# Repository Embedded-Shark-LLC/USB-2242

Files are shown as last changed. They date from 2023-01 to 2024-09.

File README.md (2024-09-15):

# USB-2242
This is a project to integrate a Logitech&trade; Unifying Receiver internally for laptops.  Specifically, I designed this to fit an M.2 2242 slot (M+B key) for my Thinkpad X1C6 (replacing the WWAN card).

If space permits, any low-power USB device (under 500 mA) can be plugged into this adapter.

## Features
- M.2 2242 form factor for internal installation
- Optional USB-A receptacle solder pads for testing/thicker laptops
- PCB cutout for minimum height when not using USB-A receptacle
- Resettable fuse to avoid overcurrent/short circuit damage

## Concept
Most thin and light laptops have a limited number of USB ports, especially USB-A ports.  Currently, my Thinkpad X1C6 has 2 USB-C and 2 USB-A ports, and I constantly leave my wireless mouse receiver in one of the USB-A ports.

After seeing similar products available for older laptop models, I couldn't find one that fit in my M.2 2242 slot, so I made my own.  All it does is provide 5V power for the USB device and routes the USB data lines according to the [M.2 specification](https://pcisig.com/specifications/pciexpress/M.2_Specification/) (local copy available [here](docs/SPEC_PCIe-M.2-Rev1.0.pdf)).

## Notice
PCB thickness must be 0.8 mm to fit in standard M.2 slots.

## Planned Features
- Separate flex PCB for easier soldering of "floating" USB device

## PCB Renders
|PCB Front|PCB Back|
|---|---|
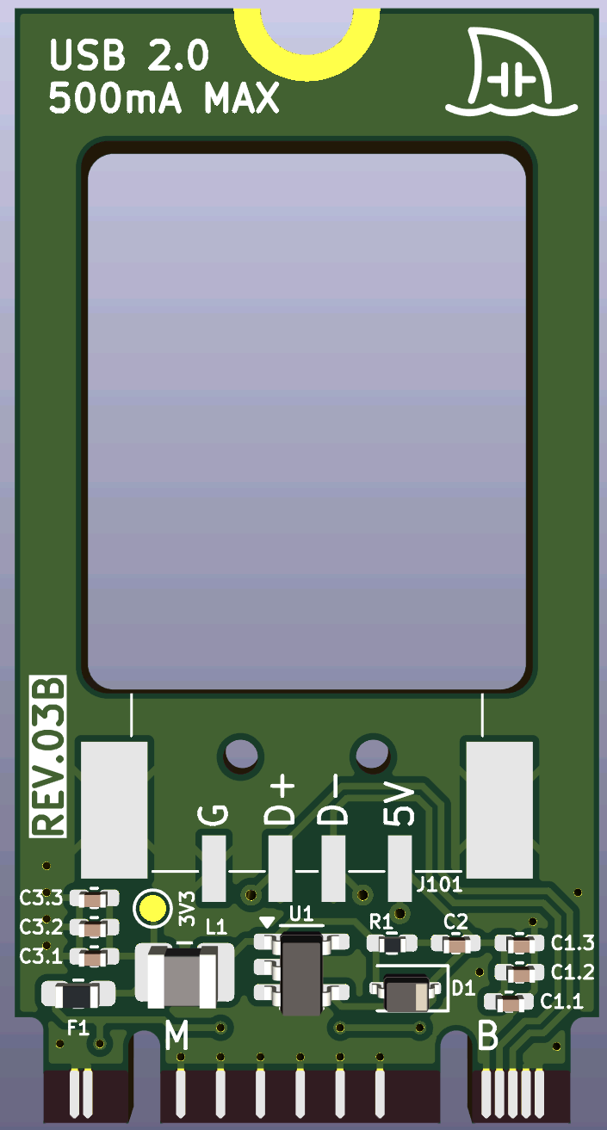
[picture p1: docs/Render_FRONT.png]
PCB front
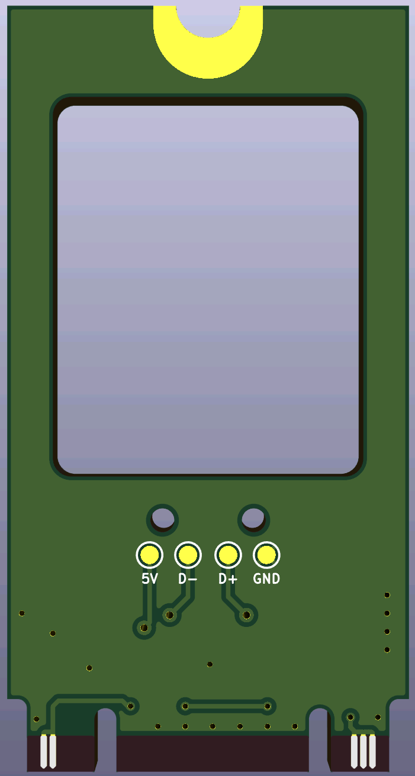
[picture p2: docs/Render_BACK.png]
PCB back
|||

## Trademark Notice
_Logitech, Logi, and their logos are trademarks or registered trademarks of Logitech Europe S.A. and/or its affiliates in the United States and/or other countries._

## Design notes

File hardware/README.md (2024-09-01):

# Hardware

## Major components
| Description | Part Number | Manufacturer | Comments |
| --- | --- | --- | --- |
| USB A port | USB-A-S-RA-TSMT | Adam Tech | SMD, right angle |
| Boost converter | TPS613222ADBVR | Texas Instruments | 5 V,  2.5 A |

## Minor components
| Description | Part Number | Manufacturer | Comments |
| --- | --- | --- | --- |
| Resettable fuse | SMD0603B050TF | YAGEO | 500 mA hold, 1 A trip, 6 V max |
| Schottky diode | CUS15S30,H3F | Toshiba Semiconductor | 30 V, 1.5 A |

## Passive components
| Description | Part Number | Manufacturer | Comments |
| --- | --- | --- | --- |
| 4.99 R resistor | RC0402FR0-74R99L | YAGEO | 0402 |
| 1 nF capacitor | 04025C102KAT2A | KYOCERA | 50 V, X7R, 0402 |
| 100 nF capacitor | CL05A104KA5NNNC | Samsung | 25 V, X5R, 0402 |
| 10 uF capacitor | GRM155R60J106ME05D | Murata Electronics | 6.3 V, X5R, 0402 |
| 22 uF capacitor | CM05X5R226M06AH080 | KYOCERA | 6.3 V, X5R, 0402 |
| 2.2 uH inductor | CIGW252010GL2R2MNE | Samsung | 93 mR DCR, 1008 |

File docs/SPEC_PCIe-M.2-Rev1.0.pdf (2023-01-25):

disclaims all warranties and liability for the use of this document and the information contained herein and assumes no responsibility for any errors that may appear in this document, nor does PCI-SIG make a commitment to update the information

Contact the PCI-SIG office to obtain the latest revision of this specification.
Questions regarding this specification or membership in PCI-SIG may be forwarded to:

Membership Services
www.pcisig.com
E-mail: | administration@pcisig.com
Phone: | 503-619-0569
Fax: | 503-644-6708

Technical Support
techsupp@pcisig.com

DISCLAIMER
This PCI Code and ID Assignment Specification is provided as is with no warranties whatsoever, including any warranty of merchantability, non-infringement, fitness for any particular purpose, or any warranty otherwise arising out of any proposal, specification, or sample. PCI-SIG disclaims all liability for infringement of proprietary rights, relating to use of information in this specification. No license, express or implied, by estoppel or otherwise, to any intellectual property rights is granted herein. PCI Express is a trademark of PCI-SIG.
All other product names are trademarks, registered trademarks, or service marks of their respective owners.
© 2012, 2013 PCI SIG. All rights reserved.

PCI Express M.2 Specification

PCI Express M.2 Specification | | 3
Revision 1.0, November 1, 2013

## Revision History

Rev | Version | History | Date
1.0 | | Initial Release | November 1, 2013

PCI Express M.2 Specification

PCI Express M.2 Specification | | 4

## Table of Contents

PCI Express M.2 Specification

PCI Express M.2 Specification | | 5
2.4.7. Top Side Connection | 63
2.4.7.1. Top Side Connector Physical Dimensions | 63
2.4.7.2. Top Side Connection Total System Length | 65
2.4.7.3. Top Side Connection Stack-up | 66
2.4.7.3.1. Single Sided Module (Using H2.3 Connector) | 66
2.4.7.3.2. Single Sided Module (Using H2.5 Connector) | 67
2.4.7.3.3. Double Sided Module (Using H2.8, H3.2 and H4.2 Connector) | 68
2.4.7.4. Top Side Connector Layout Pattern | 70
2.4.8. Mid Line Connection (Using M1.8 Connector) | 71
2.4.8.1. Mid Line Connector Physical Dimensions | 71
2.4.8.2. Mid Line Connection Total System Length | 72
2.4.8.3. Mid Line Connection Stack-up | 73
2.4.8.3.1. Single-sided Module | 73
2.4.8.3.2. Double-sided Module | 74
2.4.8.4. Mid Line Connector Layout Pattern | 76
2.4.9. Connector Key Dimension | 78
2.4.9.1. Host Connector Keying | 78
2.5. Module Stand-off | 81
2.5.1. Recommended Main Board Hole | 81
2.5.2. Electrical Ground Path | 81
2.5.3. Thermal Ground Path | 81
2.5.4. Stand-Off Guidelines | 84
2.5.4.1. Stand-Off Guidelines Option 1 | 84
2.5.4.2. Stand-Off Guidelines Option 2 | 85
2.5.5. Screw Selection Guideline | 86
2.5.5.1. Option 1, Wafer-Head Style M3 Screw | 86
2.5.5.2. Option 2, M3 Screw with Tapered Shaft | 87
2.5.5.3. Option 3, Wafer-Head Style M2 Screw | 87
2.5.5.4. Option 4, Flat-Head Style M3 Screw | 88
2.6. Thermal Guidelines for the M.2 | 89
2.6.1. Objective | 89
2.6.2. Introduction to Thermal Management | 89
2.6.2.1. Thermal Design Power Definition | 89
2.6.2.2. Skin Temperature Definition | 90
2.6.2.3. Unpowered M.2 Module Temperature | 90
2.6.2.4. System Skin Temperature—Fan-based System | 90
2.6.3. System Skin Temperature—Fanless System | 91
2.6.4. Examples of Dissipation (TDP) Response of Modules | 91

### 3. Electrical Specifications | 92

3.1. Connectivity Socket 1 Module Interface Signals | 92
3.1.1. Power Sources and Grounds | 95

PCI Express M.2 Specification

PCI Express M.2 Specification | | 6
3.1.2. PCI Express Interface | 95
3.1.3. PCI Express Auxiliary Signals | 96
3.1.3.1. Reference Clock | 96
3.1.3.2. CLKREQ# Signal | 96
3.1.3.2.1. Power-up Requirements | 98
3.1.3.2.2. Dynamic Clock Control | 98
3.1.3.3. Clock Request Support Reporting and Enabling | 100
3.1.3.4. PERST# Signal | 100
3.1.3.5. PEWAKE# Signal | 100
3.1.4. USB Interface | 101
3.1.5. Display Port Interface | 101
3.1.5.1. DP_HPD | 101
3.1.5.2. DP_MLDIR | 101
3.1.6. SDIO Interface | 102
3.1.7. UART Interface | 104
3.1.7.1. UART_WAKE# | 105
3.1.8. PCM/I2S Interface | 105
3.1.9. I2C Interface | 106
3.1.9.1. ALERT# Signal | 106
3.1.9.2. I2C_DATA Signal | 106
3.1.9.3. I2C_CLOCK Signal | 106
3.1.10. NFC Supplemental UIM Interface | 106
3.1.10.1. UIM POWER SRC | 106
3.1.10.2. UIM POWER SNK | 107
3.1.10.3. UIM SWP | 107
3.1.10.4. NFC Supplemental UIM Interface Wiring Example | 107
3.1.11. Communication Specific Signals | 108
3.1.11.1. Suspend Clock | 108
3.1.11.2. Status Indicators | 108
3.1.11.3. W_DISABLE# Signal | 109
3.1.11.4. Coexistence Signals | 110
3.1.12. Reserved Pins | 111
3.1.13. Vendor Defined | 111
3.1.14. Socket 1 Connector Pin-out Definitions | 111
3.1.15. Socket 1 Based Soldered-down Module Pinouts | 115
3.2. WWAN/SSD/Other Socket 2 Module Interface Signals | 118
3.2.1. Power Sources and Grounds | 121
3.2.2. PCI Express Interface | 121
3.2.3. USB Interface | 121
3.2.4. HSIC Interface | 121
3.2.5. SSIC Interface | 121
3.2.6. USB3.0 Interface | 122

PCI Express M.2 Specification

PCI Express M.2 Specification | | 7
3.2.7. SATA Interface (Informative) | 122
3.2.7.1. DEVSLP | 122
3.2.7.2. DAS/DSS# | 122
3.2.8. User Identity Module (UIM) Interface | 122
3.2.8.1. UIM_PWR | 122
3.2.8.2. UIM_RESET | 123
3.2.8.3. UIM_CLK | 123
3.2.8.4. UIM_DATA | 123
3.2.8.5. SIM_DETECT | 123
3.2.9. Communication-specific Signals | 124
3.2.9.1. Suspend Clock | 124
3.2.9.2. Status Indicators | 124
3.2.9.3. W_DISABLE# Signals | 124
3.2.9.4. Coexistence Signals | 124
3.2.10. Supplemental Communication Specific Signals | 125
3.2.10.1. FULL_CARD_POWER_OFF# | 125
3.2.10.2. RESET# | 125
3.2.10.3. General Purpose Input Output Pins | 126
3.2.10.3.1. GNSS Signals | 127
3.2.10.3.2. Audio Signals | 127
3.2.10.3.3. Second UIM Signals | 127
3.2.10.3.4. IPC[0..7] Signals | 128
3.2.10.3.5. WAKE_ON_WWAN# Signal | 128
3.2.10.4. DPR Signal | 128
3.2.10.5. Antenna Control | 128
3.2.11. SSD Specific Signals | 129
3.2.11.1. Reserved for MFG CLOCK and DATA | 129
3.2.12. Configuration Pins | 129
3.2.13. Socket 2 Connector Pin-out Definitions | 130
3.3. SSD Socket 3 Module Interface Signals | 136
3.3.1. Power and Grounds | 137
3.3.2. PCI Express Interface | 137
3.3.3. SATA Interface (Informative) | 137
3.3.3.1. DEVSLP | 137
3.3.3.2. DAS/DSS# | 137
3.3.4. SSD Specific Signals | 137
3.3.4.1. SUSCLK | 137
3.3.4.2. PEDET | 138
3.3.4.3. Reserved for MFG Clock & Data | 138
3.3.5. Socket 3 Connector Pin-out Definitions | 138

### 4. Electrical Requirements | 141

4.1. 3.3 V Logic Signal Requirements | 141

PCI Express M.2 Specification

PCI Express M.2 Specification | | 8
4.2. 1.8 V Logic Signal Requirements | 142
4.3. Power | 142

### 5. Platform Socket Pin-Out and Key Definitions | 145

5.1. Connectivity Socket; Socket 1 | 146
5.1.1. Socket 1-DP (Mechanical Key A) On Platform | 147
5.1.2. Socket 1-SD (Mechanical Key E) On Platform | 149
5.1.3. Dual Module Key Module: Supports Socket 1-SD and Socket 1-DP | 151
5.2. WWAN+GNSS/SSD/Other Socket; Socket 2 | 151
5.2.1. Socket 2 – Configuration Pin Definitions | 151
5.2.2. Socket 2 Pin-Out (Mechanical Key B) On Platform | 153
5.3. SSD Socket; Socket 3 (Mechanical Key M) | 155
5.4. Soldered Down Pinout Definitions | 156

### 6. Annex | 159

6.1. Glossary | 159
6.2. M.2 Signal Directions | 160
6.3. Signal Integrity Guideline | 162
6.3.1. Test Fixture Requirements | 163
6.3.2. Suggested Top Mount Signal Integrity PCB Layout | 164
6.3.3. Suggested Mid-Plane Signal Integrity PCB Layout | 167
6.4. RF Connector Related Test Setups | 173
6.4.1. VSWR Test Set-up Method for RF Connector Receptacles | 173
6.4.2. Contact Resistance Measurement Setup & Test Procedure Example | 173
6.5. Thermal Guideline Annex | 177
6.5.1. Assumptions | 177
6.5.1.1. Die Thermal Dissipation Overview | 177
6.5.1.2. Component Overview | 178
6.5.2. Generic System Environment Categories (Assumptions) | 179
6.5.2.1. Module Slot Definitions by System | 180
6.5.2.1.1. Systems with Fans | 180
6.5.2.1.2. Systems without Fans | 180
6.5.3. Assessing Thermal Design Power Capability | 181
6.5.3.1. Use Cases | 181
6.5.3.2. Extended Use Cases | 181
6.5.3.3. Unpowered Module | 181
6.5.3.4. Use Case Flexibility | 181
6.5.4. Module Placement Advice | 182
6.5.5. Skin Temperature Sensitivity to Module Power | 182
6.5.6. General Applicability | 182
6.5.7. Generic Assumptions for Module Arrangement | 182
6.5.8. Examples | 183

PCI Express M.2 Specification

PCI Express M.2 Specification | | 9
6.5.8.1. Notebook Category | 183
6.5.8.1.1. Generic Motherboard Assumptions | 184
6.5.8.1.2. System Layout Assumptions | 184
6.5.8.1.3. Local Skin Temperature | 185
6.5.8.1.4. Thermal Design Power Response – Notebook Category | 186
6.5.8.2. Thin Platform Notebook with Fan Category | 188
6.5.8.2.1. Generic Motherboard Assumptions | 189
6.5.8.2.2. System Layout Assumptions | 190
6.5.8.2.3. Module Placement Advice – Thin Platform Notebook | 190
6.5.8.2.4. Local Skin Temperature | 191
6.5.8.2.5. Thermal design Power Response – Thin Platform Notebook with Fan
Category | 192
6.5.8.3. Tablet without Fan Category | 194
6.5.8.3.1. Generic Motherboard Assumptions | 195
6.5.8.3.2. System Layout Assumptions | 196
6.5.8.3.3. Local Skin Temperature | 196
6.5.8.3.4. Thermal Design Power Response—Tablet Category | 198
6.6. Examples of FULL_CARD_POWER_OFF# Sequences (Informative) | 198
6.6.1. Example of Power On/Off Sequence | 198
6.6.2. Example of Tablet Power On/Off Sequence | 198
6.6.3. Example of Very-thin Notebooks Power On/Off Sequence | 199

### Appendix A. Acknowledgments | 200

PCI Express M.2 Specification

PCI Express M.2 Specification | | 10

## List of Figures

PCI Express M.2 Specification

PCI Express M.2 Specification | | 11
Figure 35. | Socket 1 Type 3030/3026 RF Connector Assignment Recommendation | 58
Figure 36. | Angle of Insertion | 62
Figure 37. | Point of Contact | 63
Figure 38. | Top Side Connector Dimensions | 64
Figure 39. | Top Mounting System Length | 65
Figure 40. | H2.3-S1 - Stack-up Top Mount Single-Sided Module for 1.2 Maximum Component Height 66
Figure 41. | H2.3-S2 - Stack-up Top Mount Single Sided Module for 1.35 Maximum Component Height | 66
Figure 42. | H2.3-S3 - Stack-up Top Mount Single Sided Module for 1.50 Maximum Component Height | 66
Figure 43. | H2.5-S1 - Stack-up Top Mount Single-sided Module for 1.20 Maximum Top-side Component Height and with Higher Clearance above Motherboard | 67
Figure 44. | H2.5-S2 - Stack-up Top Mount Single-sided Module for 1.35 Maximum Top-side Component Height and with Higher Clearance above Motherboard | 67
Figure 45. | H2.5-S3 - Stack-up Top Mount Single-sided Module for 1.5 Maximum Top-side Component Height and with Higher Clearance above Motherboard | 67
Figure 46. | H2.8-D4 - Stack-up Top Mount Double-sided Module for 1.5 Maximum Top-side Component Height with 0.7 Maximum Bottom-side Component Height | 68
Figure 47. | H3.2-D1 - Stack-up Top Mount Double-sided Module for 1.20 Maximum Top-side Component Height | 68
Figure 48. | H3.2-D2 - Stack-up Top Mount Double-sided Module for 1.35 Maximum Top-side Component Height | 69
Figure 49. | H3.2-D3 - Stack-up Top Mount Double-sided Module for 1.5 Maximum Top-side Component Height | 69
Figure 50. | H4.2-D5 - Stack-up Top Mount Double-sided Module for 1.5 Maximum Top-side Component Height with 1.5 Maximum Bottom-side Component Height | 69
Figure 51. | Example of Top Mount Motherboard Land Pattern Diagram Key B Shown | 70
Figure 52. | Mid-Line (In-line) Connector Dimensions | 71
Figure 53. | Mid-Line (In-Line) System Length | 72
Figure 54. | Stack-up Mid-Line (In-line) Single Sided (S1) Module for 1.2 Maximum Component Height73
Figure 55. | Stack-up Mid-Line (In-line) Single Sided (S2) Module for 1.35 Maximum Component Height | 73
Figure 56. | Stack-up Mid-Line (In-line) Single Sided (S3) Module for 1.5 Maximum Component Height74
Figure 57. | Stack-up Mid-Line (In-line) Double-sided (D1) Module for 1.2 Maximum Top-side Component Height | 74
Figure 58. | Stack-up Mid-Line (In-line) Double-sided (D2) Module for 1.35 Maximum Top-side Component Height | 75
Figure 59. | Stack-up Mid-Line (In-line) Double-sided (D3) Module for 1.5 Maximum Top-side Component Height | 75
Figure 60. | Stack-up Mid-Line (In-line) Double-sided (D4) Module for 1.5 Maximum Top-side Component Height | 75

PCI Express M.2 Specification

PCI Express M.2 Specification | | 12
Figure 61. | Stack-up Mid-Line (In-line) Double-sided (D5) Module for 1.5 Maximum Top-side and Bottom-side Component Height | 76
Figure 62. | Example of Mid Line Motherboard Land Pattern Diagram – Key B Shown | 77
Figure 63. | Connector Key | 78
Figure 64. | M.2 Connector Keying Diagram | 79
Figure 65. | Dual Module Key Scheme Example | 80
Figure 66. | Mid-Line Module Mounting Interface | 81
Figure 67. | Single-sided Top Mount Solder-down Stand-Off | 82
Figure 68. | Elevated Single-sided Top Mount Solder Stand-Off | 82
Figure 69. | Low Profile Double-sided Top Mount Solder-down Stand-Off | 82
Figure 70. | Double-sided Top Mount Solder-down Stand-Off | 83
Figure 71. | Elevated Double-sided Top Mount Solder-down Stand-off | 83
Figure 72. | Flat Stand-Off | 84
Figure 73. | Shouldered Stand-Off | 85
Figure 74. | Screw Guidelines | 86
Figure 75. | Wafer-Head Style M3 Screw | 86
Figure 76. | M3 Screw with Tapered Shaft | 87
Figure 77. | Wafer-Head Style M2 Screw | 87
Figure 78. | Flat-Head Style M3 Screw | 88
Figure 79. | Power-Up CLKREQ# Timing | 98
Figure 80. | CLKREQ# Clock Control Timings | 99
Figure 81. | SDIO Reset Sequence | 103
Figure 82. | SDIO Power-Up Sequence | 103
Figure 83. | UART Frame Format | 104
Figure 85. | Supplemental NFC Signal Connection Example | 107
Figure 86. | Typical LED Connection Example in Platform/System | 108
Figure 87. | Type 2226 SDIO Based Module-Side Pin-Out | 115
Figure 88. | Type 1216 SDIO Based Module-Side Pin-Out | 116
Figure 89. | Type 3026 Display Port Pinout Extension Over an SDIO Based Module-Side Pin-Out......117
Figure 90. | Typical SIM Detect Circuit Implementation | 124
Figure 91. | WAKE_ON_WWAN# Signal | 128
Figure 92. | Type 2226 LGA Pin-Out Using Socket 1-SD Based Pin-Out on Platform | 156
Figure 93. | Type 1216 LGA Pin-Out Using Socket 1-SD Based Pin-Out on Platform | 157
Figure 94. | Type 3026 LGA Pin-Out Using Socket 1-SD & 1-DP Based Pin-Out on Platform | 158
Figure 95. | UART and PCM Signal Direction and Signal Name Changes | 160
Figure 96. | PCIe Signal Direction and Signal Name Changes | 161

PCI Express M.2 Specification

PCI Express M.2 Specification | | 13
Figure 97. | Suggested Motherboard and Module Board Signals and Ground Pad Layout Guideline ...163
Figure 98. | Suggested Ground Void for Module Simulation | 164
Figure 99. | Suggest Ground Void for Main Board | 164
Figure 100. Top Mount Module Test Fixture PCB Layout | 165
Figure 101. Top Mount Mother Board Test Fixture PCB | 166
Figure 102. Top Mount Connector Test Fixture | 167
Figure 103. Mid Plane Connector Test Fixture | 168
Figure 104. Mid-Plane Module Test Fixture PCB Layout | 169
Figure 105. Mid Plane Mother Board Test Fixture PCB | 170
Figure 106. Detail of Top Side SMA End Launch Connector Pad | 170
Figure 107. Ground Void on Backside | 171
Figure 108. Detail of Mid Plane Vias on Top Side Mother Board | 172
Figure 109. Detail of Ground Void on Mid Plane Bottom Side Mother Board | 172
Figure 110. VSWR Test Setup for Receptacle RF Connector | 173
Figure 111. Contact Resistance Measurement Definitions | 173
Figure 112. Prepared Wires | 174
Figure 113. Prepared Wire with Plug | 175
Figure 114. Example View of Notebook Motherboard | 184
Figure 115. Example View of Edge Vents | 184

Figure 116. Example View of Bottom Vents (vent opening where inside boards are visible through the
| opening) | 185
Figure 117. Example View of Region Over Modules | 185
Figure 118. Example View of Hot Spot Over Modules | 186
Figure 119. Example View of Motherboard for Thin Platform Notebook with Fan | 189
Figure 120. Thin Platform Notebook Layout with Vents and Key Components | 190
Figure 121. Example View of Region and Hot Spots Over Modules | 191
Figure 122. Example View of Region and Hot Spots Under Modules | 192
Figure 123. Example View of Tablet Motherboard | 195
Figure 124. Example View of System Layout, Including Table | 196
Figure 125. Example View of Display Surface Temperature with WWAN Use Case Estimate II | 197

PCI Express M.2 Specification

PCI Express M.2 Specification | | 14

List of Tables

Table 1. | Optional Module Configurations | 24
Table 2. | General Tolerance | 25
Table 3. | Key Location/Pin Block Dimensions for Keys A - F | 40
Table 4. | Key Location/Pin Block Dimensions for Keys G - M | 40
Table 5. | RF Connector Physical Characteristics | 55
Table 6. | RF Connector Mechanical Requirements | 55
Table 7. | RF Connector Electrical Requirements | 56
Table 8. | RF Connector Environmental Requirements | 56
Table 9. | Recommended Antenna Function Allocation Table | 57
Table 10. | Connector/Module Type Supported Matrix | 59
Table 11. | Connector Physical Requirements | 60
Table 12. | Connector Environmental Requirements | 61
Table 13. | Connector Electrical Requirements | 61
Table 14. | Stand-Off Height Descriptor Table | 84
Table 15. | Socket 1 System Interface Signals and Voltage Table | 92
Table 16. | Power-Up CLKREQ# Timings | 98
Table 17. | CLKREQ# Clock Control Timings | 100
Table 18. | DP_MLDIR Pin Termination | 102
Table 19. | SDIO Reset and Power-Up Timing | 103
Table 20. | Simple Indicator Protocol for LED States | 109
Table 21. | Radio Operational States | 110
Table 22. | SDIO Based Module Solution Pinout (Module Key E) | 112
Table 23. | Display Port Based Module Solution Pinout (Module Key A) | 113
Table 24. | Socket 1 Module Pinout with Dual Module Key (A-E) | 114
Table 25. | Socket 2 System Interface Signal Table | 118
Table 26. | GPIO pin Function Assignment per Port Configuration | 126
Table 27. | Socket 2 Module Configuration | 129
Table 28. | Socket 2 SSIC-based WWAN Module Pinout | 131
Table 29. | Socket 2 USB3.0-based WWAN Module Pinout | 131
Table 30. | Socket 2 PCIe-based WWAN Module Pinout | 133
Table 31. | Socket 2 SATA-based SSD Module Pinout | 134
Table 32. | Socket 2 PCIe-based SSD Module Pinout | 135
Table 33. | Socket 3 System Interface Signal Table | 136

PCI Express M.2 Specification

PCI Express M.2 Specification | | 15
Table 34. | Socket 3 SATA-based Module Pinout | 139
Table 35. | Socket 3 PCIe-based Module Pinout | 140
Table 36. | DC Specification for 3.3 V Logic Signaling | 141
Table 37. | DC Specification for 1.8 V Logic Signaling | 142
Table 38. | Key Regulated Power Rail Parameters | 143
Table 39. | Power Rail Settling Time | 143
Table 40. | Key VBAT Power Rail Parameters | 143
Table 41. | Power Rating Table for the Various Modules and Connector Keys | 144
Table 42. | Mechanical Key Assignments | 146
Table 43. | Socket 1 Versions | 147
Table 44. | Socket 1-DP Pin-Out Diagram (Mechanical Key A) On Platform | 148
Table 45. | Socket 1-SD Pin-Out Diagram (Mechanical Key E) On Platform | 150
Table 46. | Socket 2 Module Configuration Table | 152
Table 47. | Socket 2 Pinout Diagram (Mechanical Key B) | 154
Table 48. | Socket 3 SSD Pin-Out (Mechanical Key M) On Platform | 155
Table 49. | Signal Integrity Requirements and Test Procedures for M.2 | 162
Table 50. | Example of Prepared Wire with Plug, Unit:mΩ | 175
Table 51. | Contact Resistance for the Sample Wires/Plugs, Unit:mΩ | 176
Table 52. | Assumptions for Typical Components and Dissipation | 177
Table 53. | Maximum Dissipation for WWAN Modules | 178
Table 54. | Generic Assumptions for Package Designations and Types Expected to Populate Modules | 178
Table 55. | Assumptions for Generic System Environments | 179
Table 56. | Slot Definitions, Systems with Fans | 180
Table 57. | Slot Definitions, Systems without Fans | 180
Table 58. | Example Use Case Applicable to Modules for Notebooks | 183
Table 59. | Thermal Design Power Response – Notebook Category | 187
Table 60. | Skin Temperature Limit Assumptions, Notebook | 187
Table 61. | Skin Temperature Effect of Module Position | 188
Table 62. | Use Cases Applicable to Modules for Thin Platform Notebook with Fan | 188
Table 63. | Thermal Design Power Response – Thin Platform Notebook with Fan Category | 193
Table 64. | Skin temperature limit assumptions, Thin platform notebook with Fan | 193
Table 65. | Use Cases Applicable to Modules for Tablet without Fan | 194
Table 66. | Thermal Design Power Response—Tablet Category | 197
Table 67. | Skin Temperature Limit Assumptions, Tablet without Fan | 198

PCI Express M.2 Specification | | 16

1

# 1. Introduction to M.2 Electro-Mechanical Specifications

The M.2 form factor is used for Mobile Add-In cards. The M.2 is a natural transition from the Mini Card and Half-Mini Card to a smaller form factor in both size and volume. The M.2 is a family of form factors that will enable expansion, contraction, and higher integration of functions onto a single form factor module solution.

The key target for M.2 is to be significantly smaller in the XYZ and overall volume of the Half-Mini Card used today in mobile platforms in preparation for the very thin computing platforms (for example Notebook, Tablet/Slate platforms) that require a much smaller solution.

The M.2 comes in two main formats:

☐ Connectorized
☐ Soldered-down

## Figure 1. M.2 Concept Board/Modules

Introduction to M.2 Electro-Mechanical Specifications

PCI Express M.2 Specification | | 17

M.2 is targeted toward addressing system manufacturers’ needs for build-to-order (BTO) and configure-to-order (CTO) rather than providing a general end-user-replaceable module. As such, the requirements provided in this document should be viewed in its entirety as an optional normative specification. It is expected that system manufacturers that build to and order modules to this specification are responsible for indicating to their module suppliers which aspects of the specification are normative, optional, or explicitly not required for the products being ordered.

# 1.1. Terms and Definitions

Host | Typically referring to the electrical interface source/master
Platform | Typically referring to the physical location. Usually a Mother Board on which the Module/Add-in Card are mounted (connectorized or soldered down)
Module | The Add-in card or device that is either plugged into the Platform connector or soldered down onto the Platform Mother Board
Add-in Card | A card or module that is plugged into a connector and mounted in a chassis socket.
x1, x2, x4 | x1 refers to one Lane of basic bandwidth; x4 refers to a collection of four Lanes; etc. This is applicable to PCIe and Display Port signals that may use Multi-Lanes

# 1.2. Targeted Application

The M.2 family of form factors is intended to support multiple function add-in cards/modules that include the following:

☐ WiFi
☐ Bluetooth
☐ Global Navigation Satellite Systems (GNSS) ☐ Near Field Communication (NFC)
☐ WiGig
☐ WWAN (2G, 3G and 4G)
☐ Solid-State Storage Devices
☐ Other & Future Solutions (e.g. Hybrid Digital Radio (HDR))

The M.2 Specification will cover multiple Host Interface solutions including:

☐ PCIe, PCIe LP
☐ HSIC
☐ SSIC

Introduction to M.2 Electro-Mechanical Specifications

PCI Express M.2 Specification | | 18

☐ USB
☐ SDIO
☐ UART
☐ PCM/ I2S

☐ I

2C
☐ SATA
☐ Display Port
☐ And future variants of the above

In light of the fact that the number of Host Interfaces has dramatically increased and in order to support the multitude of Comms and other solutions typically integrated into NB-based and very thin-based platforms, there is a need to clearly define several distinct sockets:

☐ Connectivity Socket (typically WiFi, BT, NFC or WiGig) designated as Socket 1
☐ WWAN/SSD/Other Socket that will support various WWAN+GNSS solutions, various SSD and SSD Cache configurations and potentially other yet undefined solutions designated as Socket 2
☐ SSD Drive Socket with SATA or up to 4 lanes of PCIe designated as Socket 3

Each of the three sockets is unique and incorporates a different collection of host interfaces to support the specific functionality of the modules. The modules are typically not interchangeable between sockets. Therefore, each Socket will have a unique mechanical key. However, there are cases where a dual mechanical key scheme will enable dual socket support. Details of the sockets will be described in the following sections of this document.
For the sake of coverage, the connectorized M.2 boards/modules will be defined as both single-sided for low profile solutions and dual-sided to enable more content to be integrated applicable in the platform. Several target Z-heights will be outlined as part of the specification. Actual configuration implementation will be determined between customer and vendor. A naming convention will enable an exact definition of all key parameters.

# 1.3. Specification References

This specification requires references to other specifications or documents that will form the basis for some of the requirements stated herein.

☐ PCI Express Mini Card Electromechanical Specification, Revision 2.0
☐ PCI Express Specification Revision 3.0
☐ SDIO3.0
☐ SSIC – SuperSpeed USB Inter-Chip Supplement to the USB 3.0 Specification, Revision 1.0 as of May 3, 2012
☐ HSIC - High-Speed Inter-Chip USB Electrical Specification, Version 1.0 (September 23, 2007), plus HSIC ECN Disconnect Supplement to High Speed Inter Chip Specification Revision 0.94 (Sep 20, 2012)

Introduction to M.2 Electro-Mechanical Specifications

PCI Express M.2 Specification | | 19

☐ USB2.0 - Universal Serial Bus Specification, Revision 2.0, plus ECN and Errata, July 14, 2011, available from usb.org
☐ USB3.0 - Universal Serial Bus 3.0 Specification, Revision 1 plus ECN and Errata, July 29 2011, available from usb.org
☐ DisplayPort Standard Specifications, version 1.2
☐ Serial ATA Revision 3.1 Gold or later, available from sata-io.org

☐ I

2C BUS Specifications, Version 2.1, January 2000
☐ EIA-364 Electrical Connector/Socket Test Procedures including Environmental Classifications ☐ EIA-364-1000.01: Environmental Test Methodology for Assessing the Performance of Electrical Connectors and Sockets Used in Business Office Applications

PCI Express M.2 Specification | | 20

2

# 2. Mechanical Specification

# 2.1. Overview

This specification defines a family of M.2 modules and the corresponding system interconnects based on a 75 position edge card connection scheme or a derivation of the card edge and a soldered-down scheme for system interfaces.

The M.2 family comprised of several module sizes and designated by the following names (see Figure 2):

☐ Type 1216
☐ Type 1630
☐ Type 2226
☐ Type 2230
☐ Type 2242
☐ Type 2260
☐ Type 2280
☐ Type 3026
☐ Type 3030
☐ Type 3042
☐ Type 22110

Mechanical Specification

PCI Express M.2 Specification | | 21

NOTE: KEY OPTION IS A REPRESENTATION ONLY AND DOES NOT PROHIBIT ADDITIONAL OPTIONS

TOP SIDE COMPONENT AREA TOP SIDE COMPONENT AREA

## TYPE 22110-xx-B-M Figure 2. M.2 Family of Form Factors

The majority of M.2 types are connectorized using an edge connection scheme that can be either a single-sided or dual-sided assembly. There will be several component Z-height options defined in this specification. The type of edge connector will cater to different platform Z-height requirements. In all cases, the board thickness is 0.8 mm ±10%. The type 1216, type 2226, and type 3026 are unique as they are soldered down solutions that will have an LGA pattern on the back. Therefore, they can only be single-sided and the board thickness does not need to adhere to the 0.8 mm ±10% requirement.

The edge connector requires a mechanical key for accurate alignment. The location of the mechanical key along the Gold Finger contacts will make each key unique per a given socket connector. This prevents wrongful insertion of an incompatible board which prevents a safety hazard.

The board type, the type of assembly, the component Z-heights on top and bottom, and the mechanical key will make up the M.2 board naming convention detailed in the next section.

PCI Express M.2 Specification | | 22

# 2.2. Card Type Naming Convention

Because there are various types of M.2 solutions and configurations, a standard naming convention will be employed to define the main features of a specific solution.

The naming convention will identify the following:

☐ The module size (width & length)
☐ The component assembly maximum Z-height for the top and bottom sides of the module
☐ The Mechanical Connector Key/Module key location/assignment or multiple locations/assignments

These naming conventions will clearly define the module functionality, what connector it coincides with, and what Z-heights are met. Figure 3 diagrams the naming convention.

The board width options are: 12 mm, 16.5 mm, the generic 22 mm, and the widest 30 mm board width.

The board length can scale to various lengths to support the content and expand as the content increases. The lengths supported are: 16 mm, 26 mm, 30 mm, 42 mm, 60 mm, 80 mm, and 110 mm.

Together these two dimensions make up the first part of the module type definition portion of the module name.

The next part of the name describes whether the module is single-sided or dual-sided and a secondary definition of what are the maximum Z-heights of the components on the top and bottom side of the module. Here we have specific Z-height limits that are either 1.5 mm, 1.35 mm, or
1.2 mm on the top side and 1.5mm, 1.35 mm, 0.7 mm and 0 mm on the bottom side. The letter S will designate Single-sided and the letter D will designate Dual-sided. This will be complimented with a number that designates the specific Z-height combination option.
The last section of the name will designate the mechanical connector key/module key name and the coinciding pin location. These will be designated by a letter from A to M. In cases where the module will have a dual key scheme to enable insertion of the module into two different keyed sockets, a second letter will be added to designate the second mechanical connector key/module key.

Key ID assignment must be approved by the PCI-SIG. Unauthorized Key IDs would render the modules incompatible with the M.2 specification.

Figure 4 on the following page shows an example of module Type 2242 – D2 – B – M.

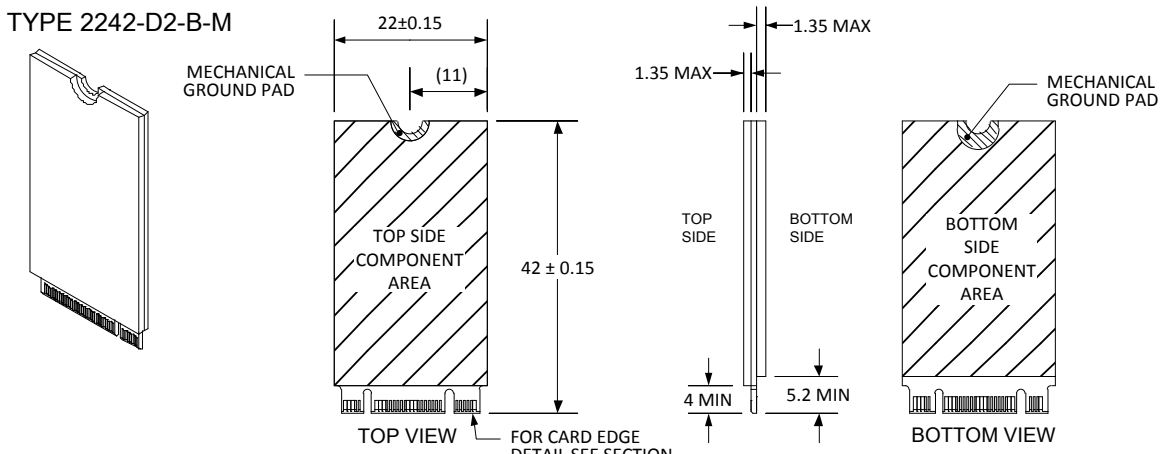
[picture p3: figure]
TOP VIEW; TYPE 2242-D2-B-M; BOTTOM VIEW; MECHANICAL GROUND PAD; 1.35 MAX; 4 MIN; 5.2 MIN; TOP SIDE; BOTTOM TOP SIDE; SIDE COMPONENT AREA; BOTTOM SIDE COMPONENT AREA

PCI Express M.2 Specification | | 23
Revision 1.0, November 1, 2013 | Top Max Lable**
S1 | 1.2

Module Nomenclature Sample Type 2242-D2-B-M Type XX XX - XX - X - Xâ

Width (mm) 12

16

22

30

Length (mm) 16

26

30

42

60

80

110

Key ID

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
8-15
12-19 16-23 20-27 24-31 28-35 39-46 43-50 47-54 51-58 55-62 59-66

Interface 2x PCIe x1 / USB 2.0 / I2C / DP x4 PCIe x2/SATA/USB 2.0/USB 3.0/HSIC/SSIC/Audio/UIM/I2C Reserved for Future Use Reserved for Future Use 2x PCIe x1 / USB 2.0 / I2C / SDIO / UART / PCM Future Memory Interface (FMI) Generic (Not used for M.2)*** Reserved for Future Use Reserved for Future Use Reserved for Future Use Reserved for Future Use PCIe x4 / SATA

S2

S3

D1

D2

D3

Component Max Ht (mm) 1.35

1.5

1.2

1.35

1.5

Bottom Max 0**** 0****

0****

1.35

1.35

1.35 D4

D5 | 1.5
1.5 | 0.7

1.5

- Use ONLY when a double slot is being specified
| Label included in height dimension
| Key G is intended for custom use. Devices with this key will not be M.2-compliant. Use at your own risk!
Insulating label allowed on connector-based designs

## Figure 3. M.2 Naming Nomenclature

FOR CARD EDGE DETAIL SEE SECTION 2.3.5

## Figure 4. Example of Type 2242-D2-B-M Nomenclature

The board is 22 mm x 42 mm, Double Sided with a maximum Z-height of 1.35 mm on both the Top and Bottom, and it has two mechanical connector keys/module keys at locations B and M which will enable it to plug into two types of connectors (Key B or Key M).

Table 1 shows the various options for board configurations as a function of the Socket, Module Function and Module size.

PCI Express M.2 Specification | | 24

Type 1216, Type 2226 and Type 3026 are unique as they are Soldered-Down solutions while all the others are connectorized with a PCB Gold Finger layout that coincides with an Edge Card connector. The Soldered-Down solutions do not have mechanical keys and their pin-out configuration needs to be specifically called out.

Table 1. | Optional Module Configurations
| Soldered-down | | | Connectorized
Socket 1 Connectivity | 1216 | S1, S3 | E | N/A | N/A | N/A | N/A
| N/A | N/A | N/A | A, E | 1630 | S1, D1, S3, D3, D4 | A, E, A+E
| 2226 | S1, S3 | E | A, E | 2230 | S1, D1, S3, D3, D4 | A, E, A+E
| 3026 | S1, S3 | A+E | A, E | 3030 | S1, D1, S3, D3, D4 | A, E, A+E
Socket 2 WWAN/Other | N/A | N/A | N/A | B | 3042 | S1, D1, S3, D3, D4 | B
Socket 2 SSD/Other | N/A | N/A | N/A | B | 2230 | S2, D2, S3, D3, D5 | B+M
| N/A | N/A | N/A | B | 2242 | S2, D2, S3, D3, D5 | B+M
| N/A | N/A | N/A | B | 2260 | S2, D2, S3, D3, D5 | B+M
| N/A | N/A | N/A | B | 2280 | S2, D2, S3, D3, D5 | B+M
| N/A | N/A | N/A | B | 22110 | S2, D2, S3, D3, D5 | B+M
Socket 3 SSD Drive | N/A | N/A | N/A | M | 2242 | S2, D2, S3, D3, D5 | M, B+M
| N/A | N/A | N/A | M | 2260 | S2, D2, S3, D3, D5 | M, B+M
| N/A | N/A | N/A | M | 2280 | S2, D2, S3, D3, D5 | M, B+M
| N/A | N/A | N/A | M | 22110 | S2, D2, S3, D3, D5 | M, B+M

Type

Module Height
Options

Pinout
Key

Connector
Key Type

Module Height
Options

Module
Key

PCI Express M.2 Specification | | 25

# 2.3. Card Specifications

There are multiple defined card outlines. Card thickness is fixed at 0.8 mm ±10% with optional increased/decreased XY dimensions so as to incorporate more or less functionality on the board.

For purposes of the drawings in this specification, the following notes apply:

☐ All dimensions are in millimeters (mm), unless otherwise specified
☐ All dimension tolerances are ± 0.15 mm, unless otherwise specified
☐ Insulating material shall not interfere with or obstruct mounting holes or grounding pads
☐ The board/module has a 4 mm tall strip at the lower end of the board intended to support the Gold Finger pads used in conjunction with an Edge Card connector. The Gold Fingers appear on both top and bottom side of the board/module PCB
☐ In some configuration, the board/module has a 3.8 mm strip intended to support RF connectors ☐ All connectorized versions have a mounting/retention screw (half-moon cutout) at the upper end of the board/module used to hold down the board onto the Motherboard or chassis
☐ The remainder of the board area available is intended for Active Components but not limited to this. Encroachment into this area can be done if extra area is needed for additional RF antenna connectors
☐ The diagrams showing mechanical connector key/module key locations in this document are for example only. Actual Key location/definition is part of the actual module name per the naming convention
☐ General Tolerance Summary as given in Table 2
Table 2. | General Tolerance
+ Plus | – Minus
PCB Size Tolerance | 0.15 mm | 0.15 mm
PCB Thickness | 0.08 mm | 0.08 mm
Bevel Capabilities | 0.25 mm | 0.25 mm
Drill Capabilities for Module key | 0.05 mm | 0.05 mm

PCI Express M.2 Specification | | 26

## 2.3.1. Card Form Factors Intended for Connectivity Socket 1

## 2.3.1.1. Type 2230 Specification

The Generic M.2 board/module size used for the majority of the Connectivity solutions such as WiFi+BT type solutions is Type 2230. However, this board size can also accommodate other Multi-Comm and Combo solutions as well.
The Type 2230 board/module is intended to support the multiple WiFi configurations such as 1x1, 2x2, and 3x3. An example of the Type 2230 board/module mechanical outline drawing is shown in Figure 5 and Figure 6.
The Type 2230 board/module uses a 75 position host interface connector and has room to support up to four (4) RF connectors in the upper section. The recommended location and assignment of the four RF connectors is described in section 2.3.7, RF Connectors. RF connectors may be placed in other locations on the Type 2230 board/module. In cases where additional RF connectors are needed, they can be added in the active component area and should maintain a minimal distance of 4.5 mm center-to-center to enable manufacturing test interface of the RF connection.

The diagrams in Figures 5 and 6 are an example of specific board type(s).

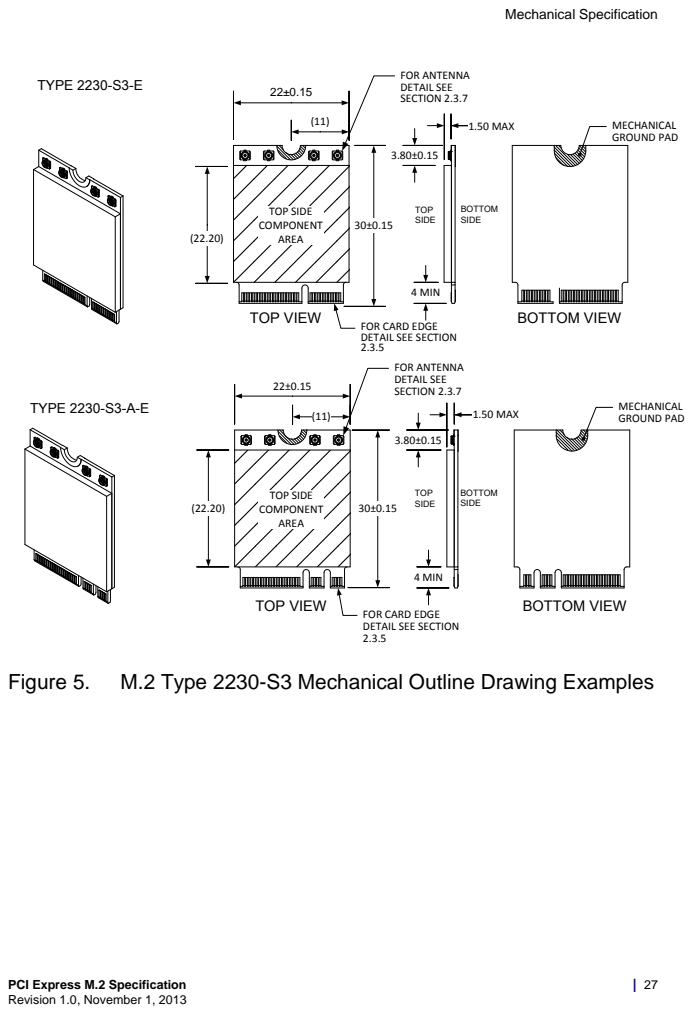
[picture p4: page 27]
PCI Express M.2 Specification; TYPE 2230-S3-A-E; TOP VIEW; BOTTOM VIEW; 4 MIN; 1.50 MAX (22.20); TOP SIDE COMPONENT AREA; MECHANICAL GROUND PAD TYPE 2230-S3-E; (11) 1.50 MAX; BOTTOM VIEW ⁴ MIN TOP SIDE COMPONENT (22.20); AREA; Figure 5.; M.2 Type 2230-S3 Mechanical Outline Drawing Examples

FOR ANTENNA DETAIL SEE SECTION 2.3.7

BOTTOM SIDE TOP SIDE

FOR CARD EDGE DETAIL SEE SECTION 2.3.5

MECHANICAL GROUND PAD FOR ANTENNA DETAIL SEE SECTION 2.3.7

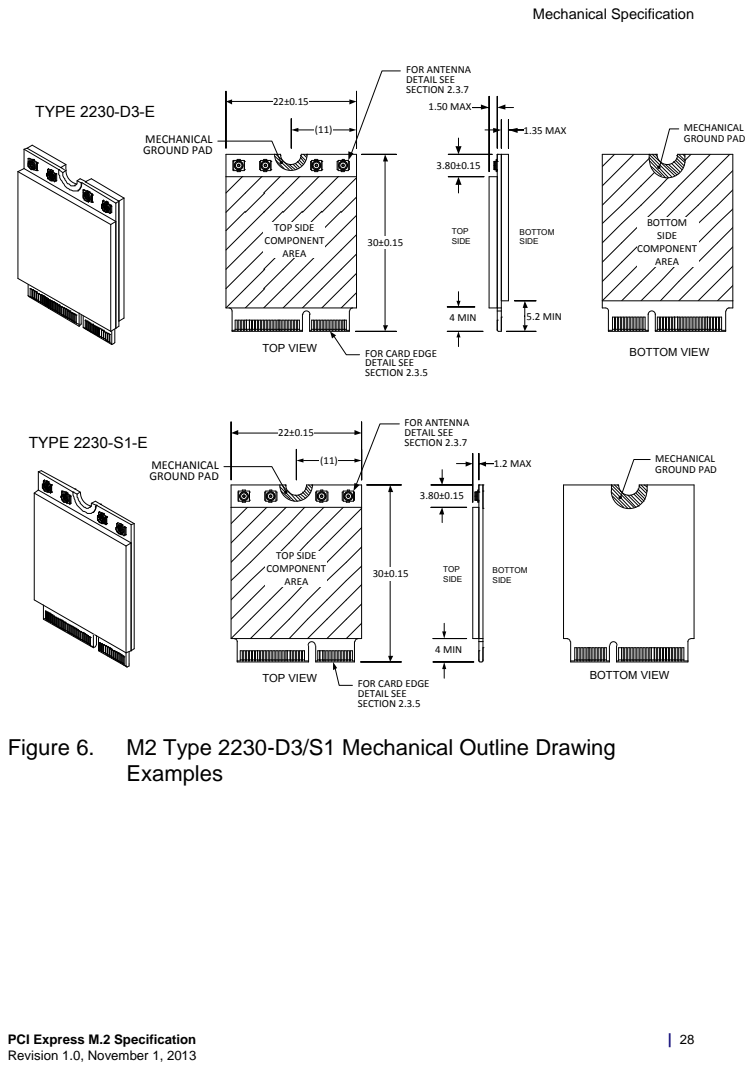
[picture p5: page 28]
PCI Express M.2 Specification; TYPE 2230-S1-E; MECHANICAL GROUND PAD TYPE 2230-D3-E; 4 MIN TOP SIDE COMPONENT AREA; BOTTOM SIDE COMPONENT AREA; TOP VIEW; BOTTOM VIEW; TOP SIDE; BOTTOM SIDE; MECHANICAL GROUND PAD; 1.50 MAX; 1.35 MAX; FOR ANTENNA DETAIL SEE SECTION 2.3.7; 1.2 MAX; 5.2 MIN; Figure 6.; M2 Type 2230-D3/S1 Mechanical Outline Drawing; Examples

FOR ANTENNA DETAIL SEE SECTION 2.3.7

FOR CARD EDGE DETAIL SEE SECTION 2.3.5

4 MIN TOP SIDE COMPONENT AREA

PCI Express M.2 Specification | | 29

## 2.3.1.2. Type 1630 Specification

Type 1630 is a smaller M.2 board/module size used for single Comm or more simplistic Comm combo solutions such as WiFi 1x1 or 2x2 + BT only or future multi-comm solutions that can fit in a smaller footprint.

The Type 1630 is a subset of the Type 2230 board with 5.5 mm sliced off along the entire length of the board. Therefore it is inherently limited in the number of RF connections and has a reduced number of pins used in the Host Interface connector.
Because the Type 1630 board/module utilizes only the first 57 pin locations (a mechanical key uses 8 pins and the connector uses 49 pins for the host interface), it is limited in its connection capability. Thus it is limited in the number of Comms that can be simultaneously supported on such a board/module.

The mounting hole and the mechanical key are exactly the same as those in the Type 2230 so that in principle the Motherboard Socket can support both Type 2230 and Type 1630.

Note: Board/module Type 1630 is limited to Key ID A thru H only.

An example of the Type 1630 board/module mechanical outline drawing is shown in Figure 7.

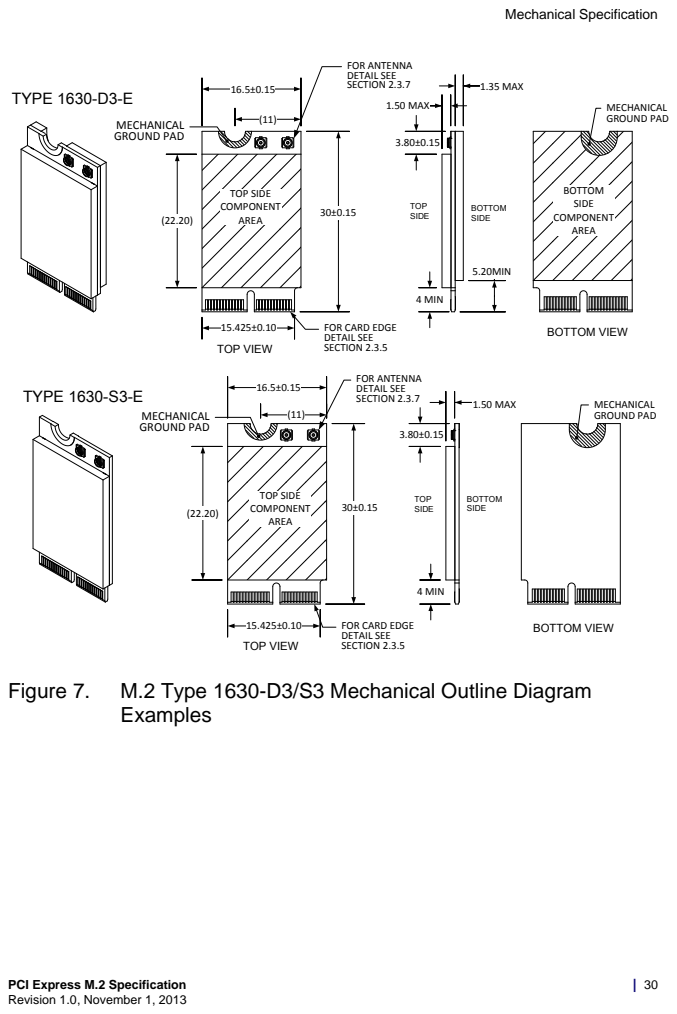
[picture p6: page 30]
PCI Express M.2 Specification; TYPE 1630-S3-E; FOR ANTENNA DETAIL SEE SECTION 2.3.7; FOR CARD EDGE DETAIL SEE SECTION 2.3.5; BOTTOM VIEW TOP VIEW; TOP SIDE; BOTTOM SIDE MECHANICAL GROUND PAD; MECHANICAL GROUND PAD 16.5±0.15; 4 MIN; 1.50 MAX; TYPE 1630-D3-E; TOP VIEW; BOTTOM SIDE; BOTTOM VIEW; MECHANICAL GROUND PAD; TOP SIDE COMPONENT AREA; BOTTOM SIDE COMPONENT AREA; 5.20MIN; 3.80±0.15 1.50 MAX; 1.35 MAX; Figure 7.; M.2 Type 1630-D3/S3 Mechanical Outline Diagram; Examples

FOR ANTENNA DETAIL SEE SECTION 2.3.7 16.5±0.15

FOR CARD EDGE DETAIL SEE SECTION 2.3.5

30±0.15 TOP SIDE COMPONENT AREA

PCI Express M.2 Specification | | 31

## 2.3.1.3. Type 3030 Specification

Type 3030 is an extended width M.2 board/module size used for more complex Comm combo solutions.

In principle the board is still comprised of three sections:
☐ Host I/F section
☐ RF connector and mounting hole section
☐ Active Component section

The active component section is 8 mm wider making an overall width of 30 mm (instead of the generic 22 mm width). The length remains the same at 30 mm so that it coincides with the other Type xx30 boards/modules.

An example of the Type 3030 board/module mechanical outline drawing is shown in Figure 8. The wider board size will support a greater number of RF connectors. Up to six (6) RF connectors can be populated while maintaining the recommended 4.5 mm center-to-center distances. See section 2.3.7, RF Connectors in this document for recommended locations and assignments.

FOR CARD EDGE DETAIL SEE SECTION 2.3.5

## Figure 8. M.2 Type 3030-S3 Mechanical Outline Diagram Example

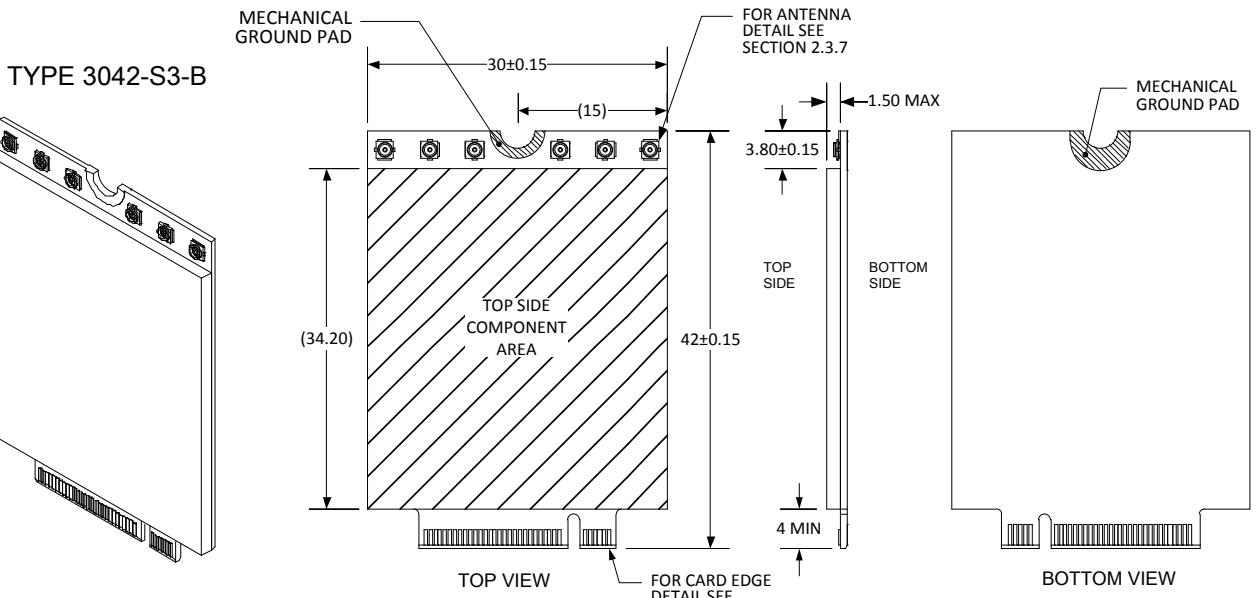
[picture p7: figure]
1.50 MAX 3.80±0.15; 4 MIN; TYPE 3042-S3-B; TOP VIEW; TOP SIDE; BOTTOM SIDE; BOTTOM VIEW; MECHANICAL GROUND PAD; FOR ANTENNA DETAIL SEE SECTION 2.3.7; TOP SIDE COMPONENT AREA

PCI Express M.2 Specification | | 32

## 2.3.2. Card Form Factor Intended for WWAN Socket 2

## 2.3.2.1. Type 3042 Specification

Type 3042 is an extended-width M.2 board/module size used for WWAN solutions.

In principle the board is still comprised of three sections:
☐ Host I/F section
☐ RF connector and mounting hole section
☐ Active Component section
The active component section is 8 mm wider making it wider than other board/module alternatives intended for Socket 2 with the same overall length of 42 mm.
An example of the Type 3042 board/module mechanical outline drawing is shown in Figure 9.

The wider board size will support a greater number of RF connectors. Up to six (6) RF connectors can be populated while maintaining the recommended 4.5 mm center-to-center distances. See section 2.3.7, RF Connectors in this document for recommended locations and assignments.

FOR CARD EDGE DETAIL SEE SECTION 2.3.5

## Figure 9. M.2 Type 3042-S3 Mechanical Outline Diagram Example

PCI Express M.2 Specification | | 33

## 2.3.3. Card Form Factor for SSD Socket 2

## 2.3.3.1. Type 2230 Specification

Type 2230 is a M.2 board/module size used on Socket 2 and intended to support SSD Cache solutions and possibly other PCI Express based solutions. In principle the board is still comprised of two sections:
☐ Host I/F section
☐ Active Component section

The active component section including the mounting hole area has an overall length of 26 mm top side and 24.8 mm bottom side when applicable. Figure 10 shows Type 2230 board/module mechanical outline drawing.

1.35 MAX TYPE 2230-D2-B | 1.35 MAX TOP SIDE COMPONENT AREA | BOTTOM SIDE COMPONENT AREA
TOP VIEW | FOR CARD EDGE | BOTTOM VIEW DETAIL SEE SECTION 2.3.5

FOR CARD EDGE DETAIL SEE SECTION 2.3.5

## Figure 10. M.2 Type 2230-S2/D2 Mechanical Outline Diagram Examples

PCI Express M.2 Specification | | 34

## 2.3.4. Card Form Factors for SSD Socket 2 and 3

## 2.3.4.1. Type 2242 Specification

Type 2242 is a M.2 board/module size used on Socket 2 and intended to support SSD solutions and possibly other PCI Express based solutions. In principle the board is still comprised of two sections: ☐ Host I/F section
☐ Active Component section

The active component section including the mounting hole area has an overall length of 38 mm top side and 36.8 mm bottom side when applicable. Figure 11 shows Type 2242 board/module mechanical outline drawing. The SSD module can take advantage of the Dual Module key scheme to enable this module to plug into two different SSD-capable Sockets (for example; Socket 2 and Socket 3).

TYPE 2242-D2-B-M | (11) 22±0.15
TOP VIEW | BOTTOM VIEW FOR CARD EDGE DETAIL SEE SECTION 2.3.5
TOP SIDE COMPONENT AREA | BOTTOM SIDE COMPONENT AREA TOP SIDE | BOTTOM SIDE MECHANICAL GROUND PAD | MECHANICAL GROUND PAD
4 MIN | 5.20 MIN 42±0.15
1.35 MAX | 1.35 MAX
MECHANICAL GROUND PAD TYPE 2242-D2-B | (11) 22±0.15

TOP VIEW

TOP SIDE | BOTTOM SIDE

BOTTOM VIEW

MECHANICAL GROUND PAD

FOR CARD EDGE DETAIL SEE SECTION 2.3.5

TOP SIDE COMPONENT AREA | BOTTOM SIDE COMPONENT AREA 42±0.15
4 MIN | 5.20 MIN
1.35 MAX | 1.35 MAX

## Figure 11. M.2 Type 2242-D2 Mechanical Outline Diagram Examples

## 2.3.4.2. Type 2260 Specification

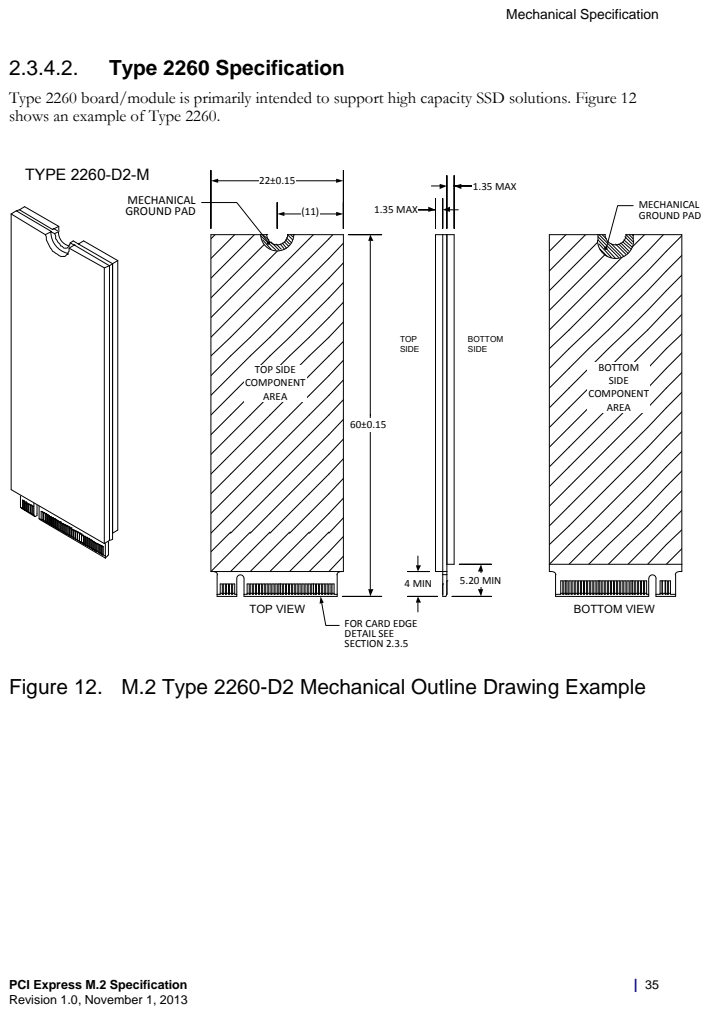
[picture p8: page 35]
PCI Express M.2 Specification; (11) TYPE 2260-D2-M; TOP VIEW; TOP SIDE; BOTTOM SIDE; BOTTOM VIEW; MECHANICAL GROUND PAD; TOP SIDE COMPONENT AREA; BOTTOM SIDE COMPONENT AREA; 1.35 MAX; 4 MIN; 5.20 MIN

Type 2260 board/module is primarily intended to support high capacity SSD solutions. Figure 12
shows an example of Type 2260.

FOR CARD EDGE DETAIL SEE SECTION 2.3.5

Figure 12. M.2 Type 2260-D2 Mechanical Outline Drawing Example

## 2.3.4.3. Type 2280 Specification

This board/module type is primarily intended to support high-capacity SSD solutions.
Figure 13 shows an example of board Type 2280.

TOP SIDE COMPONENT AREA

FOR CARD EDGE DETAIL SEE SECTION 2.3.5

Figure 13. M.2 Type 2280-S2 Mechanical Outline Drawing Example

## 2.3.4.4. Type 22110 Specification

## (11) 1.35 MAX TYPE 22110-D2-M

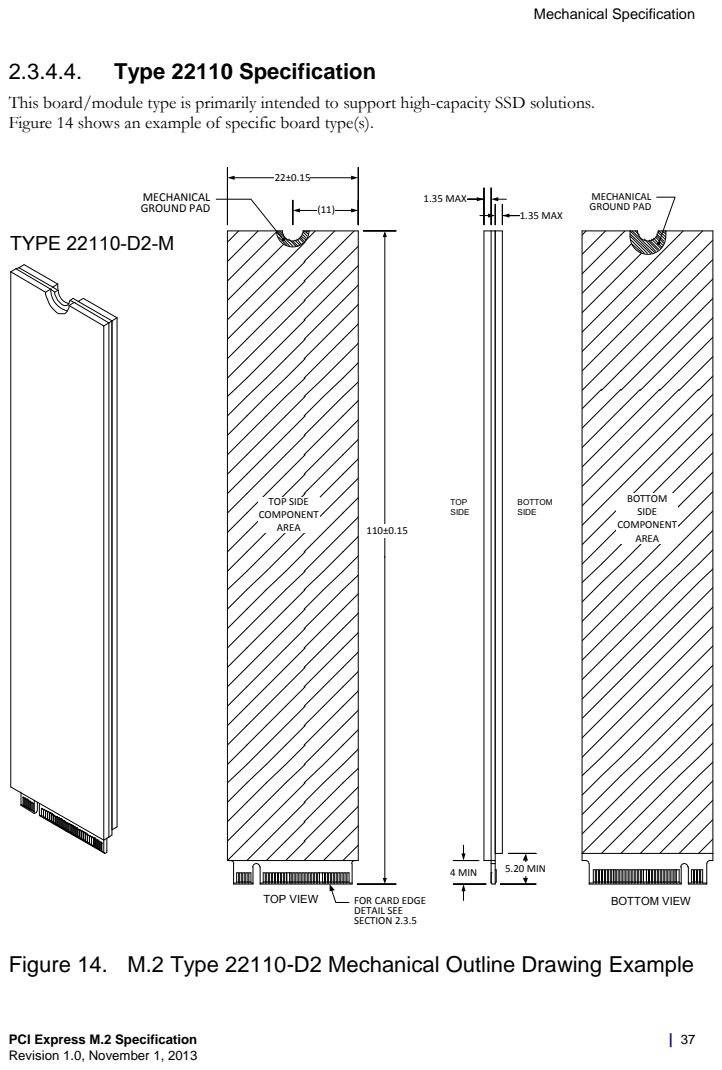
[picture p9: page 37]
PCI Express M.2 Specification; TOP VIEW; TOP SIDE; BOTTOM SIDE; BOTTOM VIEW; MECHANICAL GROUND PAD; TOP SIDE COMPONENT AREA; BOTTOM SIDE COMPONENT AREA; 4 MIN; 5.20 MIN; 1.35 MAX 22±0.15

This board/module type is primarily intended to support high-capacity SSD solutions.
Figure 14 shows an example of specific board type(s).

FOR CARD EDGE DETAIL SEE SECTION 2.3.5

Figure 14. M.2 Type 22110-D2 Mechanical Outline Drawing Example

PCI Express M.2 Specification | | 38

## 2.3.5. Card PCB Details

## 2.3.5.1. Mechanical Outline of Card-Edge

Figure 15, Figure 16, and Figure 17 show typical card-edge mechanical outlines.

C

2X 0.30±0.25 0.80±0.08 GOLD FINGER TO GOLD FINGER

## Figure 15. Card Edge Bevel

MECHANICAL GROUND PAD NO COMPONENTS ALLOWED

AREA RESERVED FOR RF RECEPTACLES OR COMPONENTS WHEN NO RF RECEPTACLES USED

4 MIN for Top Side Component Zone Limit COMPONENT AREA

Figure 16. Card Edge Outline-Topside

Optional Bottom Side Component Zone Limit

2X R 0.50±0.15 Figure 17. Card Edge Outline-Backside

PCI Express M.2 Specification | | 40

## 2.3.5.2. Module Keying

Note: Key G is shown for reference only! This Key is allocated for custom use at one’s own risk. It is not used for M.2 spec compliant devices

Keying is required to provide configurability as well as preventing incompatible module insertion. See the following figures and tables for dimensional values.

☐ Figure 18. Key Detail for Keys A Thru F
☐ Figure 19. Key Detail for Keys G Thru M
☐ Table 3. | Key Location/Pin Block Dimensions for Keys A - F
☐ Table 4. | Key Location/Pin Block Dimensions for Keys G - M
☐ Figure 20. Dual Key A-E Example
☐ Figure 21. Dual Key B-M Example

The key locations and pin block dimensions for Keys A thru F are listed in Table 3. Table 4 lists Keys G thru M .The key designation identifier should be marked with either Silk Screen, reverse copper etching, or solder mask removal on the Top-side of the module board to the right of the module key, as shown in Figure 18 and Figure 19. The letter size should be at least 1 mm tall.

Table 3. | Key Location/Pin Block Dimensions for Keys A - F
Dimension | Key ID
A | B | C | D | E | F
Q | 6.625 | 5.625 | 4.625 | 3.625 | 2.625 | 1.625
R | 1.50 | 2.50 | 3.50 | 4.50 | 5.50 | 6.50
S | 14.50 | 13.50 | 12.50 | 11.50 | 10.50 | 9.50
T | 1.00 | 2.00 | 3.00 | 4.00 | 5.00 | 6.00
U | 14.50 | 13.50 | 12.50 | 11.50 | 10.50 | 9.50
Table 4. | Key Location/Pin Block Dimensions for Keys G - M
Dimension | Key ID
G | H | J | K | L | M
V | 1.125 | 2.125 | 3.125 | 4.125 | 5.125 | 6.125
W | 9.00 | 10.00 | 11.00 | 12.00 | 13.00 | 14.00
X | 7.00 | 6.00 | 5.00 | 4.00 | 3.00 | 2.00
Y | 9.00 | 10.00 | 11.00 | 12.00 | 13.00 | 14.00
Z | 6.50 | 5.50 | 4.50 | 3.50 | 2.50 | 1.50

Two Key designation identifiers should be marked when the module employs a dual module key scheme as shown in Figure 20 and Figure 21 respectively.

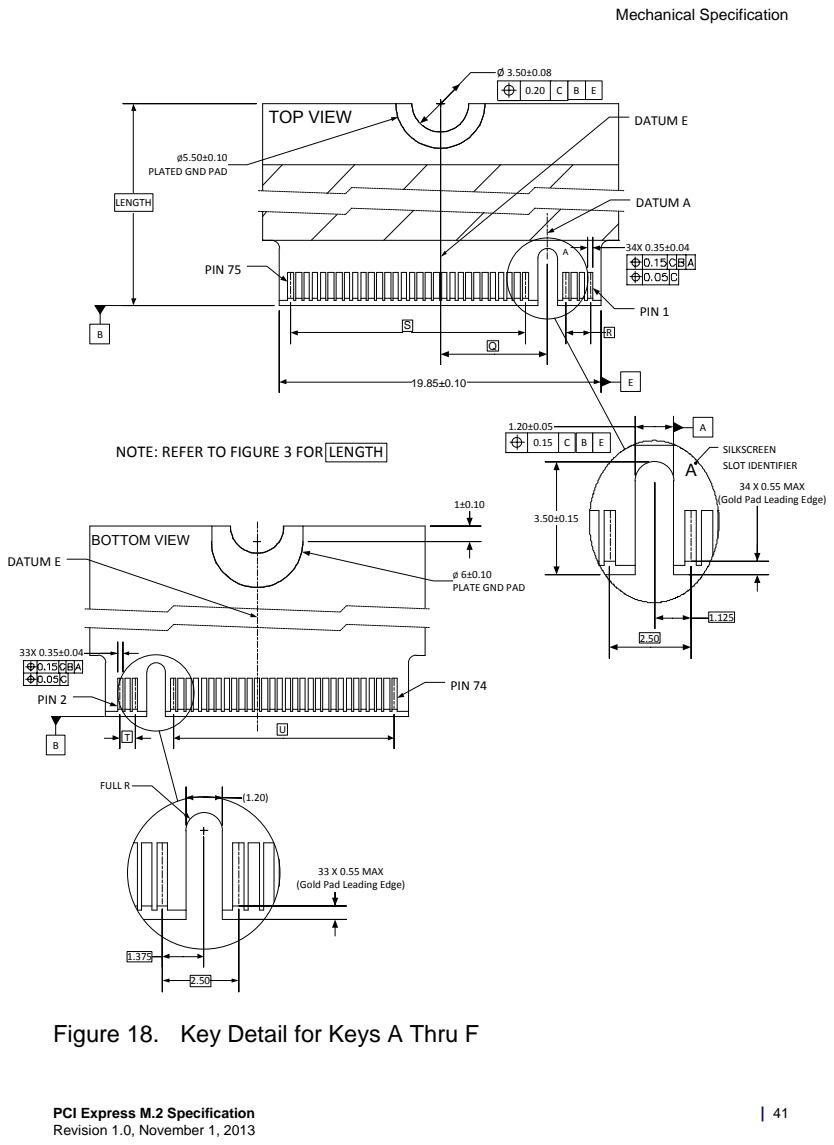
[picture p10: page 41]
PCI Express M.2 Specification; Revision 1.0, November 1, 2013; 1±0.10 BOTTOM VIEW; (1.20) FULL R; PIN 2; PIN 74; TOP VIEW; Ø5.50±0.10 PLATED GND PAD; PIN 1 PIN 75; LENLGTH; DATUM A; DATUM E; SILKSCREEN SLOT IDENTIFIER 1.20±0.05; NOTE: REFER TO FIGURE 3 FOR LENGTH; 34 X 0.55 MAX (Gold Pad Leading Edge)

Ø 6±0.10 PLATE GND PAD

33 X 0.55 MAX (Gold Pad Leading Edge)

Figure 18. Key Detail for Keys A Thru F

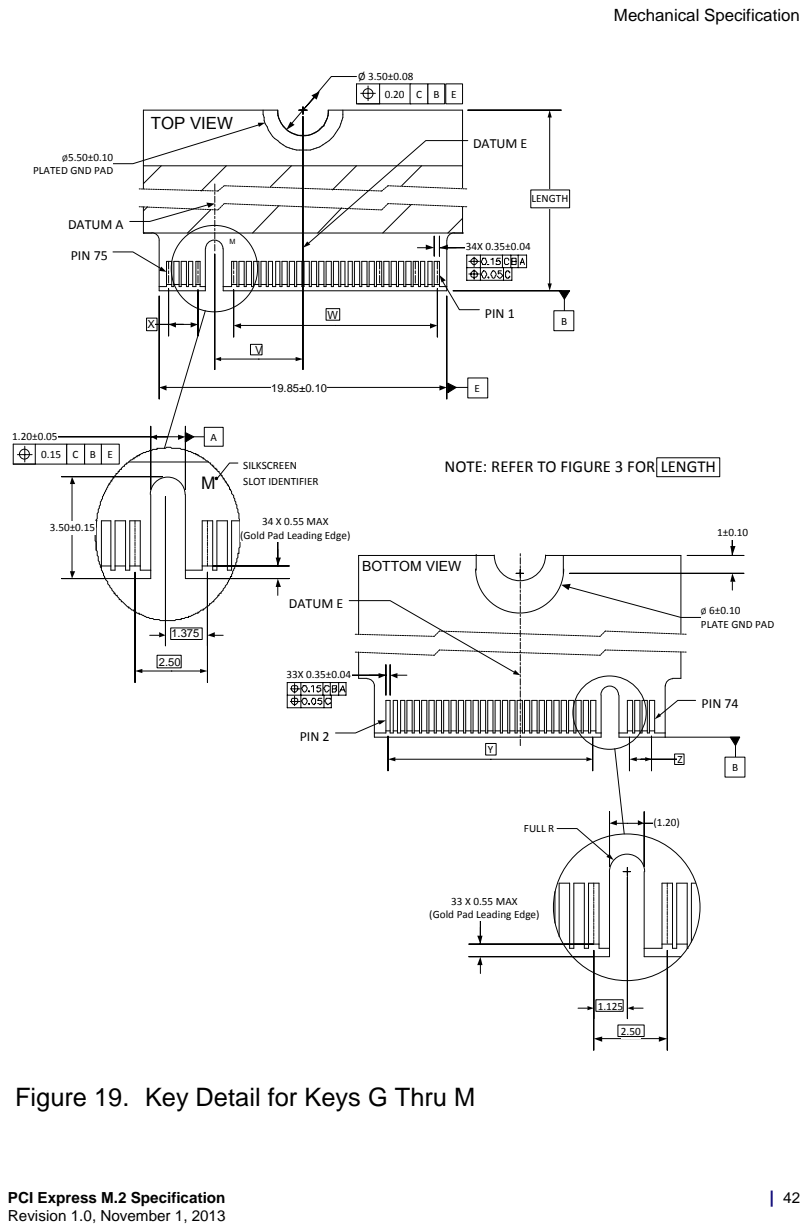
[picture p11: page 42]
PCI Express M.2 Specification; TOP VIEW; SILKSCREEN SLOT IDENTIFIER A; PIN 75; PIN 1; Ø5.50±0.10 PLATED GND PAD; DATUM A; LENLGTH; DATUM E; PIN 2; BOTTOM VIEW; (1.20) FULL R; Ø 6±0.10 PLATE GND PAD 33X 0.35±0.04; PIN 74

NOTE: REFER TO FIGURE 3 FOR LENGTH 34 X 0.55 MAX (Gold Pad Leading Edge)

33 X 0.55 MAX (Gold Pad Leading Edge)

Figure 19. Key Detail for Keys G Thru M

30 X 0.55 MAX (Gold Pad Leading Edge)

NOTE: REFER TO FIGURE 3 FOR LENGTH

Figure 20. Dual Key A-E Example

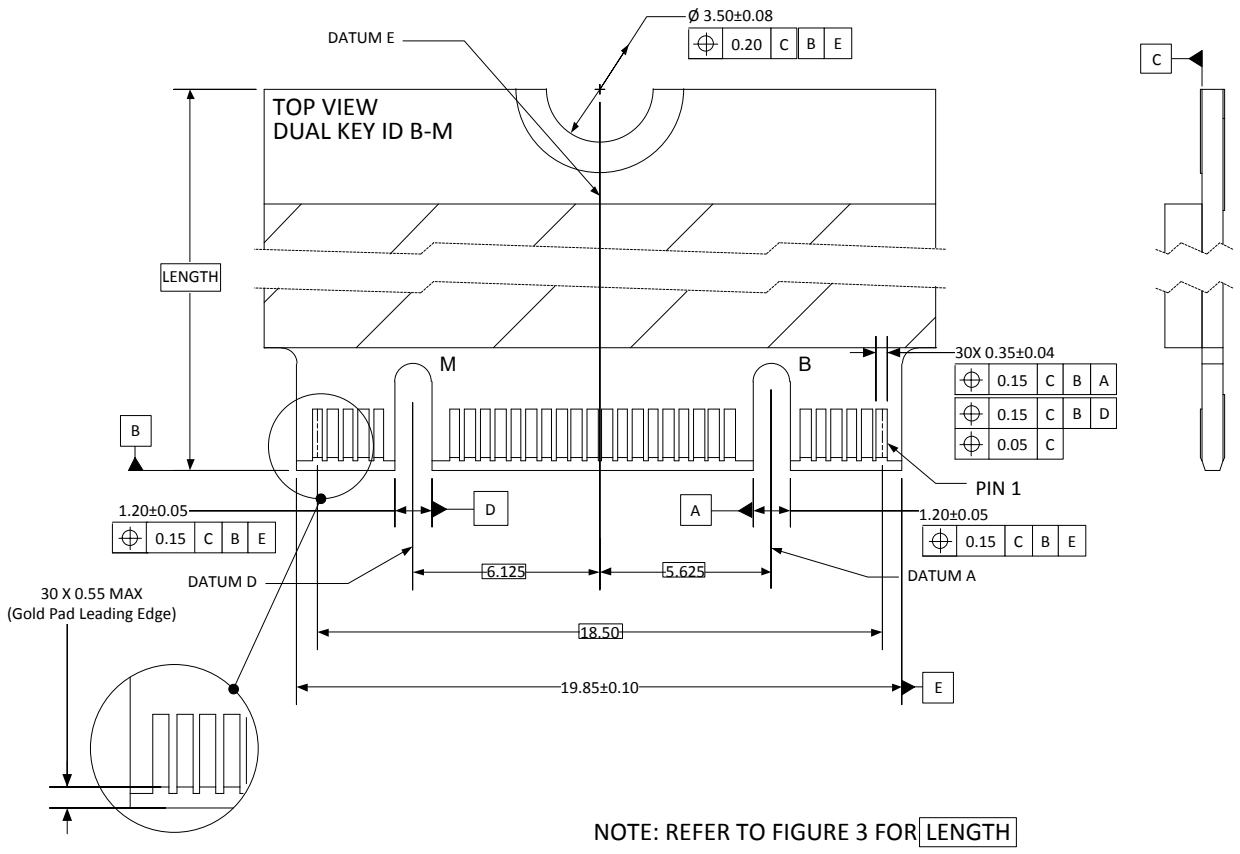
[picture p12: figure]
DATUM A DATUM D; DATUM E TOP VIEW DUAL KEY ID B-M; PIN 1; LENLGTH; NOTE: REFER TO FIGURE 3 FOR LENGTH; 30 X 0.55 MAX (Gold Pad Leading Edge)

PCI Express M.2 Specification | | 44

## Figure 21. Dual Key B-M Example

## 2.3.6. Soldered-down Form Factors

## 2.3.6.1. Type 2226 Specification

Type 2226 board/module is a soldered-down, single sided version of Type 2230 board/module. It is therefore assuming the same board technology and silicon package technology. It has an LGA land pattern on the backside instead of the 75 position Host Interface Edge Card gold finger connector. As a result of this, Type 2226 is 4 mm shorter.

To help prevent module-warp, it is recommended to balance the copper area of the PCB layers. The guideline recommendation is for the difference between copper area of mirrored layers (i.e. outer to outer layer, first inner on top to first inner on bottom, etc.) to be equal to or less than 15%.
Figure 22 shows the mechanical outline drawing for board/module Type 2226. The recommended land pattern is given in Figure 23.

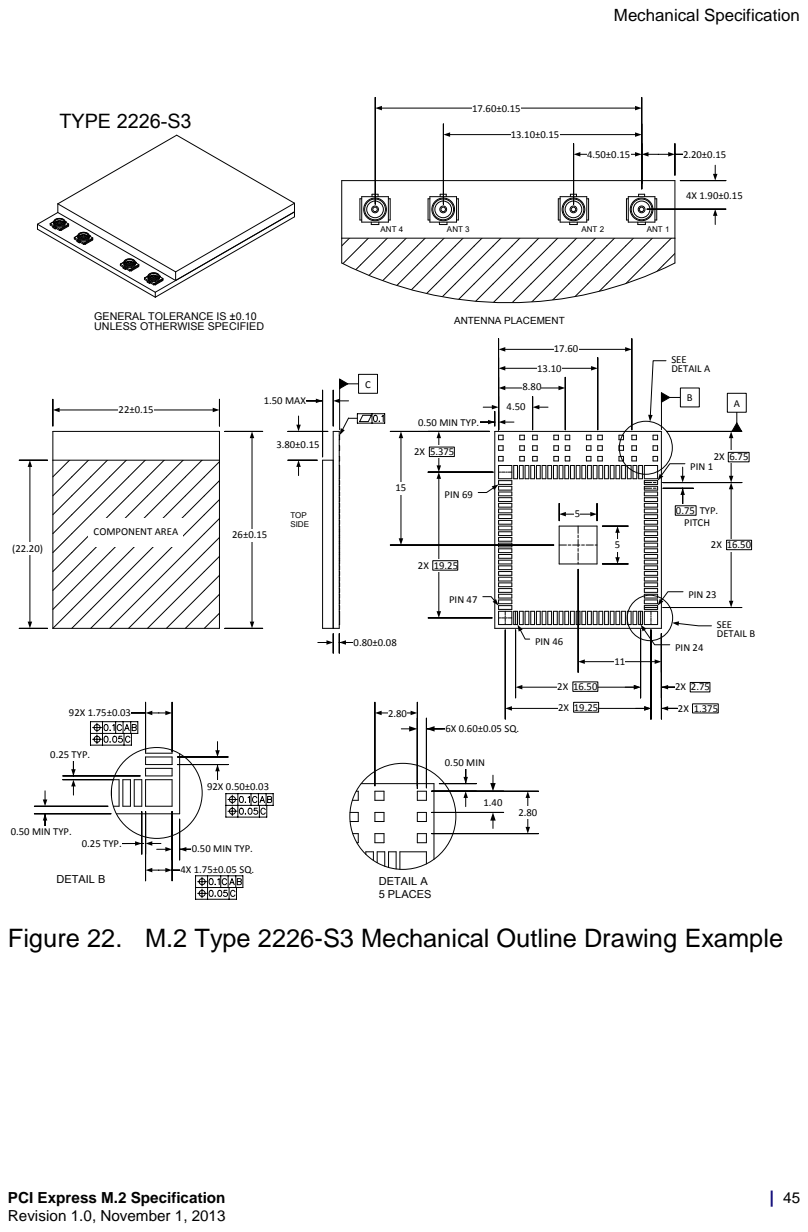
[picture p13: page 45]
PCI Express M.2 Specification; TYPE 2226-S3; COMPONENT AREA; TOP SIDE; 1.50 MAX; ANTENNA PLACEMENT ANT 4; ANT 3; ANT 2; ANT 1; SEE DETAIL B 11 2X 16.50 2X 19.25; 0.50 MIN TYP. 15; PIN 69; PIN 47; PIN 46; PIN 24; PIN 23; PIN 1; 2X 16.50 0.75 TYP. PITCH; SEE DETAIL A; DETAIL A 5 PLACES; 6X 0.60±0.05 SQ. 0.50 MIN; 4X 1.75±0.05 SQ. 0.25 TYP. DETAIL B; 0.50 MIN TYP.; 92X 0.50±0.03 0.50 MIN TYP.; 0.25 TYP.

GENERAL TOLERANCE IS ±0.10 UNLESS OTHERWISE SPECIFIED

Figure 22. M.2 Type 2226-S3 Mechanical Outline Drawing Example

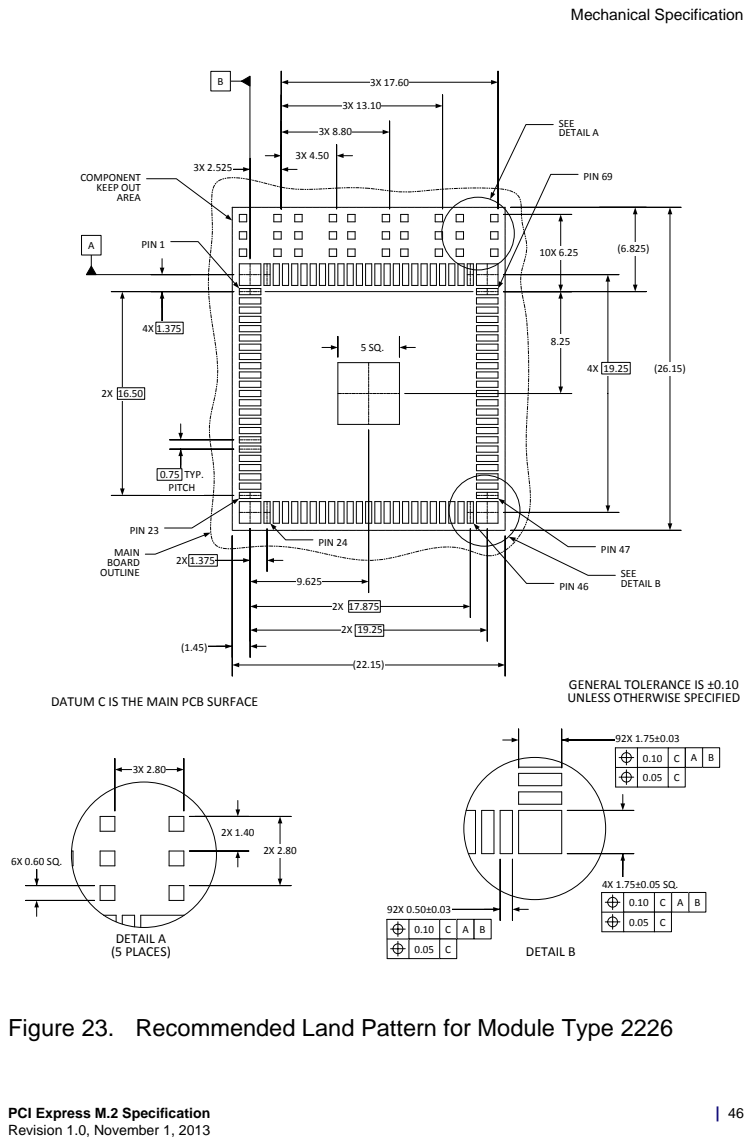
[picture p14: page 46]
PCI Express M.2 Specification; DATUM C IS THE MAIN PCB SURFACE; GENERAL TOLERANCE IS ±0.10 UNLESS OTHERWISE SPECIFIED; 4X 1.75±0.05 SQ. DETAIL B; DETAIL A (5 PLACES); PIN 69; SEE DETAIL A; PIN 47 PIN 46; SEE DETAIL B PIN 24 0.75; TYP. PITCH; PIN 23; PIN 1

COMPONENT KEEP OUT AREA

MAIN BOARD OUTLINE

Figure 23. Recommended Land Pattern for Module Type 2226

PCI Express M.2 Specification | | 47

## 2.3.6.2. Type 1216 Specification

This board/module type is another single-sided soldered-down solution based on a higher density interconnect technology and a smaller silicon package technology. It has an LGA land pattern on the backside and therefore the size is smaller.

To help prevent module-warp, it is recommended to balance the copper area of the PCB layers. The guideline recommendation is for the difference between copper area of mirrored layers (for example, outer to outer layer, first inner on top to first inner on bottom, etc.) to be equal to or less than 15%. Figure 24 shows the mechanical outline drawing for board/module Type 1216. The recommended land pattern is given in Figure 25.

GENERAL TOLERANCE IS ±0.10 UNLESS OTHERWISE SPECIFIED

8X 3 SQ. CENTERLINE OF 16 (PB)

Figure 24. Type 1216-S3 Soldered Down Solution Module Diagram

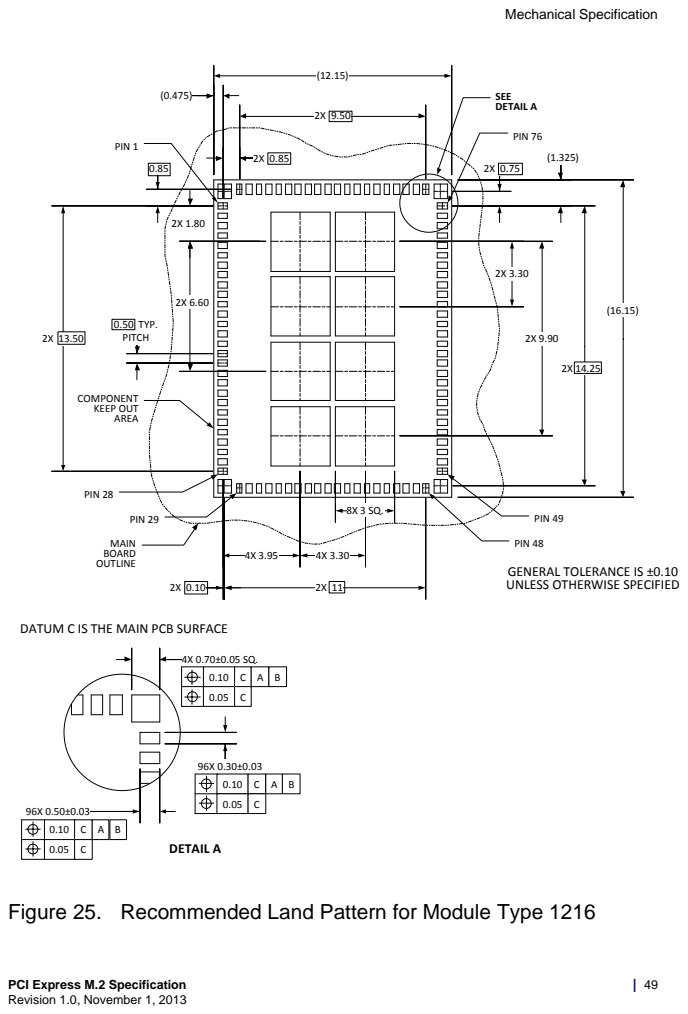
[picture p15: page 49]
PCI Express M.2 Specification; (12.15) PIN 1; PIN 28; 2X 6.60 0.50 TYP. PITCH; SEE DETAIL A; PIN 76; PIN 49 PIN 48 PIN 29 MAIN BOARD OUTLINE; DETAIL A; DATUM C IS THE MAIN PCB SURFACE; GENERAL TOLERANCE IS ±0.10 UNLESS OTHERWISE SPECIFIED

COMPONENT KEEP OUT AREA

Figure 25. Recommended Land Pattern for Module Type 1216

PCI Express M.2 Specification | | 50

## 2.3.6.3. Type 3026 Specification

This board/module type is a single sided soldered-down version of the Type 3030 board/module and assumes the same board and silicon package technology. It has a unique LGA land pattern on the backside instead of the 75 position Host Interface Edge Card gold finger connector. This LGA pattern can accommodate a Type 2226 module as a drop-in replacement located at the center with two sets of LGA pads along the sides that cover the entire 3026 module size. Like the Type 2226 module, the module size is also 4 mm shorter than the Edge Card gold finger version.

To help prevent the module from warping, it is recommended to balance the copper area of the PCB layers. The guideline recommendation is for the difference between copper area of mirrored layers (for example; outer-to-outer layer, first inner on top to first inner on bottom, etc.) to be equal to or less than 15%.
Figure 26 shows the mechanical outline drawing for board/module Type 3026. See Figure 27 for more detailed information. The recommended land pattern is given in Figure 28.
GENERAL TOLERANCE IS ±0.10 UNLESS OTHERWISE SPECIFIED | C 1.50 MAX

3.80±0.15

0.80±0.08

TOP SIDE

6.20±0.15 4.50±0.15 | 4.50±0.15 17.60±0.15 4.50±0.15 | 4.50±0.15 ANT 5 | ANT 4 | ANT 3 | ANT 2 | ANT 1 ANT 0 COMPONENT AREA

## Figure 26. M.2 Type 3026-S3 Mechanical Outline Drawing Example

6X Ø0.80 ANTENNA THRU HOLE (OPTIONAL)

Figure 27. M.2 Type 3026-S3 Mechanical Outline Drawing Details

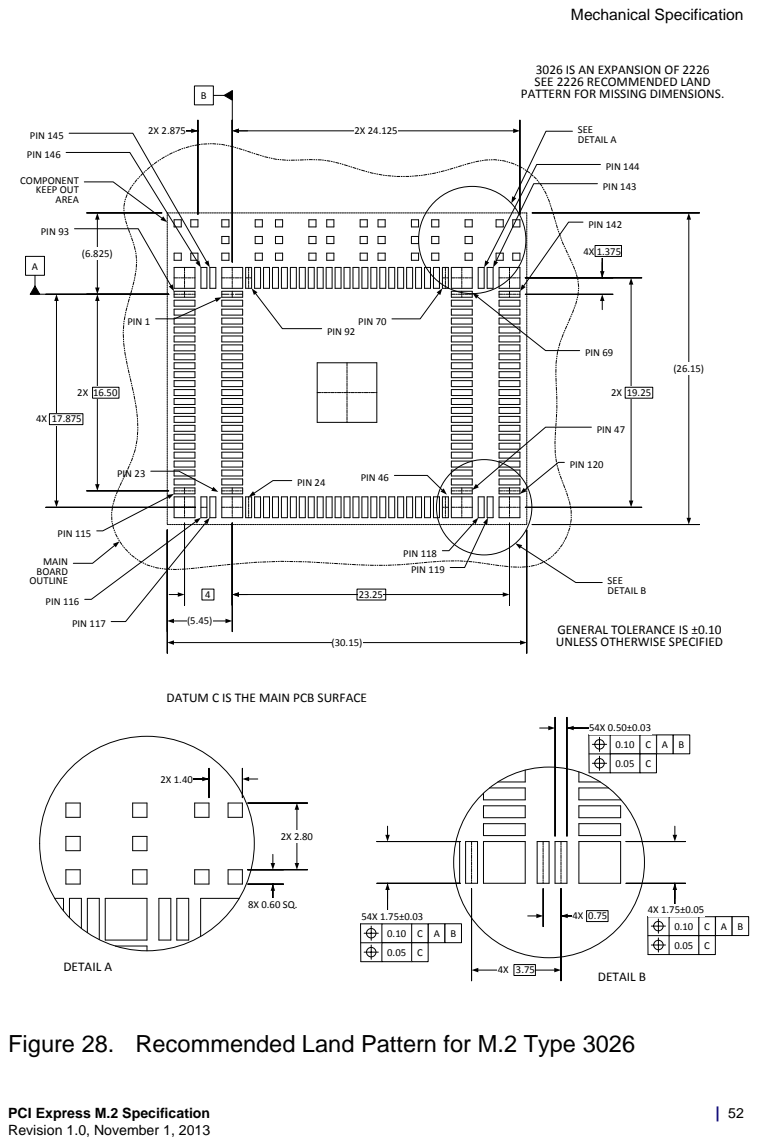
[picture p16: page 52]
PCI Express M.2 Specification; DATUM C IS THE MAIN PCB SURFACE; GENERAL TOLERANCE IS ±0.10 UNLESS OTHERWISE SPECIFIED ⁴; DETAIL A; DETAIL B; COMPONENT KEEP OUT AREA; SEE DETAIL A; SEE DETAIL B; PIN 1 PIN 93; PIN 146 PIN 145; PIN 143 PIN 144; PIN 142; PIN 116; PIN 117; 3026 IS AN EXPANSION OF 2226 SEE 2226 RECOMMENDED LAND PATTERN FOR MISSING DIMENSIONS.; PIN 23; PIN 24; PIN 46; PIN 47

PIN 69 PIN 70 PIN 92

PIN 120 PIN 118 PIN 119 PIN 115

MAIN BOARD OUTLINE

Figure 28. Recommended Land Pattern for M.2 Type 3026

PCI Express M.2 Specification | | 53

## 2.3.7. RF Connectors

The top end of the wireless module board area is the preferred location for the RF connectors. However, other areas can be used in cases that this area is not enough at the expense of the component area (Figure 29).

The standard 2x2 mm size RF receptacle connectors (Figure 30) to be used in conjunction with the M.2 boards/modules will accept two types of mating plugs that will meet a maximum Z-height of 1.45 mm (Figure 31) utilizing a Ø 1.13 mm coax cable or a maximum Z-height of 1.2 mm using a Ø 0.81 mm coax cable (Figure 32). Figure 33 shows the antenna connector designation scheme.

## (22) CONTACT Figure 29. Board Type 2230 Antenna Connector Designation

## Scheme

## Figure 30. Generic 2x2 mm RF Receptacle Connector Diagram

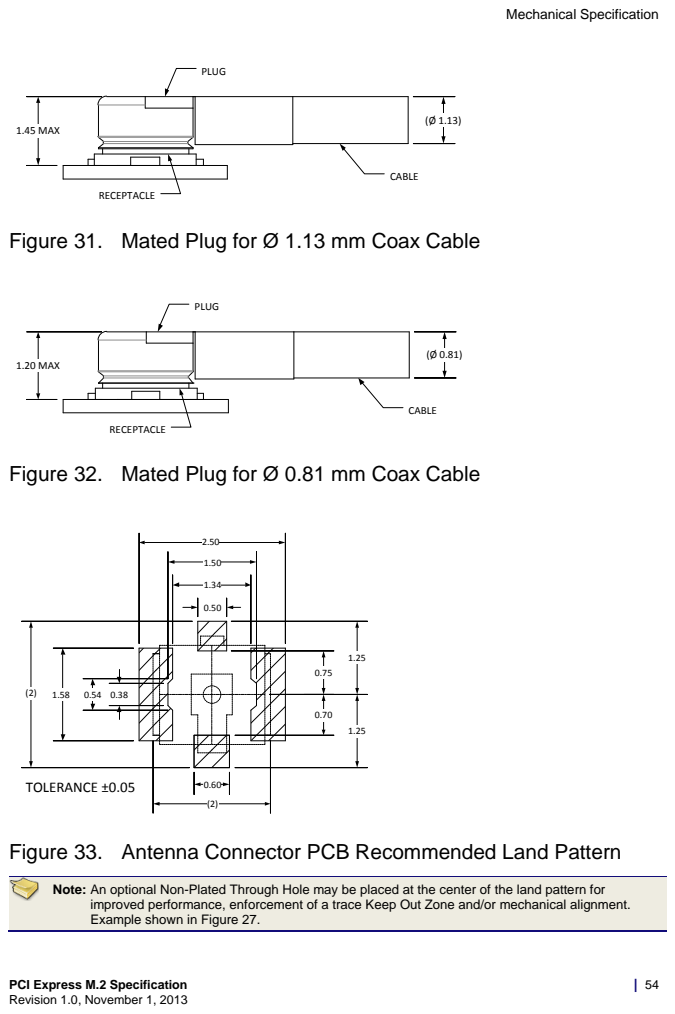
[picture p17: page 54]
PCI Express M.2 Specification; CABLE RECEPTACLE; PLUG 1.45 MAX; PLUG 1.20 MAX

Figure 31. Mated Plug for Ø 1.13 mm Coax Cable

Figure 32. Mated Plug for Ø 0.81 mm Coax Cable

1.25 TOLERANCE ±0.05 Figure 33. Antenna Connector PCB Recommended Land Pattern

Note: An optional Non-Plated Through Hole may be placed at the center of the land pattern for

improved performance, enforcement of a trace Keep Out Zone and/or mechanical alignment.
Example shown in Figure 27.

PCI Express M.2 Specification | | 55

The minimum requirements for the RF Connector are listed in Tables 5 through 9.

Table 5. | RF Connector Physical Characteristics
Characteristic | Description
Receptacle Physical Outline | 2 x 2 x 0.60 mm
Receptacle OD | 1.5 mm
Housing Material | High Temperature Plastic
Flammability | UL 94-V0
Contact Material | Copper Alloy/Gold Plating
Ground Contact Material | Copper Alloy/Gold Plating
Table 6. | RF Connector Mechanical Requirements
Description | Standard Requirement | Improved Requirement
Mating force | 30 N Maximum
Un-mating force | 5 N Initial, 3 N Minimum after 30 cycles, 20 N Maximum
Cable Retention at 0 Degree Pull (Parallel to PCB) | 5 N Minimum | 20 N Minimum (Ø 1.13 mm wire) 10 N Minimum (Ø 0.81 mm wire)
Cable Retention at 30 Degree Pull (PCB to Cable Angle) | Not Recommended | 10 N Minimum
Durability (# of mating cycles) | 30 cycles (Contact Resistance-20 mΩ)
Receptacle Shearing Strength | 20 N Minimum
Vibration | No momentary disconnections of 1 µs Minimum

PCI Express M.2 Specification | | 56
Table 7. | RF Connector Electrical Requirements
Description | Requirements
Voltage Rating | 60 V AC
Current Rating | 1.0 A Maximum
Impedance | 50 Ω
Receptacle VSWR- 100 MHz to about ~3 GHz⁽¹⁾ | 1.3 Maximum
Receptacle VSWR- 3 GHz to ~6 GHz⁽¹⁾ | 1.45 Maximum
Optional Enhanced Frequency Receptacle VSWR- 3 GHz to ~12 GHz⁽¹,2) | 2.0 Maximum
Contact Resistance | Inner: 20 mΩ Maximum

Outer: 20 mΩ Maximum

Initial: 20 mΩ Maximum

Dielectric Withstanding Voltage | 200 V AC for one minute
Insulation Resistance | 500 mΩ for one minute at 100 V DC

Note: (1) The VSWR of the receptacle is measured differently than the VSWR of the mating plug (see Section 6.4).
(2) The optional Enhanced frequency performance to 12 GHz to be provided upon specific request.
Table 8. | RF Connector Environmental Requirements
Description | Requirement
Operating Temperature Range | -40˚C to +85˚C
Humidity | 90%
Soldering Heat Resistance | Lead Free Reflow up to 260˚C peak for 10 s
RoHs Compliant/Halogen Free | Must be compliant

PCI Express M.2 Specification | | 57

## 2.3.7.1. Socket 1 & 2 RF Connector Pin-Out

The RF Connector area will allow two (2), three (3), four (4), or six (6) RF connectors to be placed as a function of the board Type:

☐ Type 22xx can support up to four RF Connectors
☐ Type 1630 can support up to two RF Connectors
☐ Type 30xx can support up to six RF Connectors
☐ Type 1216 can support up to three RF Connectors

To remain consistent with the Host I/F pin order, the RF connectors are labeled ANT0, ANT1, ANT2, ANT3, ANT4, and ANT5 from right to left. The recommended antenna function allocation is given in Table 9.

Table 9. | Recommended Antenna Function Allocation Table
Type | ANT5 | ANT4 | ANT3 | ANT2 | ANT1 | ANT0
Socket 1 WiFi+BT+Other (Type 1630, 2230, 3030, 2226) | N/A | Other Comm (when applicable) | WiFi3 (when applicable) | WiFi1 | WiFi2+BT | N/A
Socket 2 WWAN+GNSS (Type 3042) | Vendor Specific | Vendor Specific | Vendor Specific | Vendor Specific | Vendor Specific | Vendor Specific
Type 1216 | N/A | N/A | Vendor Specific | Vendor Specific | Vendor Specific | N/A

Note: Actual RF connector functions to be defined by vendorcustomer if not using the recommended allocations in this table.
ANT0 and ANT5 are an expansion of the basic four antenna connections (ANT1-ANT4) when the board is 30 mm wide

The recommended WiFi antenna port assignment implies that the main WiFi antenna port (for example; WiFi 1x1) would use ANT2 and listed as WiFi1. When WiFi expands to a 2x2 configuration, it should share the antenna port with the BT using ANT1. This is listed as WiFi2+BT. In extended WiFi 3x3 solutions, the third antenna port used is ANT3 and this is listed as WiFi3. Other Comms should use ANT4 when more complex wireless Combo solutions are implemented.

Figure 34 and Figure 35 show Socket 1 Type 2230 and 3030 RF connector assignment recommendations.

Socket 2 Type 3042 RF connector assignment recommendations are vendor-specific.

GENERAL TOLERANCE IS ±0.15 (22)

Figure 34. Socket 1 Type 2230/2226 RF Connector Assignment

GENERAL TOLERANCE IS ±0.15

Figure 35. Socket 1 Type 3030/3026 RF Connector Assignment

PCI Express M.2 Specification | | 59

# 2.4. System Connector Specifications

The card interconnect is based on a 75 position Edge Card connector. The 75 position connector is intended to be keyed so as to distinguish between families of Host Interfaces and the various Sockets used in NB/very thin platforms and Tablet platforms. This specification document makes provision for the following three Socket families:

☐ Connectivity Socket 1
☐ WWAN/SSD/Other Socket 2
☐ SSD Drive Socket 3

In order to accommodate various product Z-height limitations, there will be generic types of Edge Connectors in multiple height variants designated below:

☐ M1.8 - Mid Line (1.80 Max Ht.) – For very low profile platforms
☐ H2.3 - Top Side – Single Sided (2.25 mm Max Ht.) Connector
☐ H2.5 - Top Side – Single Sided (2.45 mm Max Ht.) Connector ☐ H2.8 – Top Side – Dual Sided (2.75 mm Max Ht.) Connector ☐ H3.2 – Top Side – Dual Sided (3.20 mm Max Ht.) Connector
☐ H4.2 – Top Side – Dual Sided (4.20 mm Max Ht.) Connector

Note: This list of connector options is not exclusive; other connector designs are allowable per market needs, however they must meet normative mechanical and electrical requirements contained within this document.

Table 10 lists the module types supported by the different connector types.

Table 10. | Connector/Module Type Supported Matrix
Description | Component Height Descriptors
S1 | S2 | S3 | D1 | D2 | D3 | D4 | D5
M1.8 | Mid-plane Connector | ✓ | ✓ | ✓ | ✓ | ✓ | ✓ | ✓ | ✓
H2.3 | Single-Sided (2.25 Max Ht.) Connector | ✓ | ✓ | ✓
H2.5 | Single-Sided (2.45 Max Ht.) Connector | ✓ | ✓ | ✓
H2.8 | Double-Sided (2.75 Max Ht.) Connector | ✓ | ✓ | ✓ | | | | ✓
H3.2 | Double-Sided (3.2 Max Ht.) Connector | ✓ | ✓ | ✓ | ✓ | ✓ | ✓ | ✓
H4.2 | Double-Sided (4.2 Max Ht.) | ✓ | ✓ | ✓ | ✓ | ✓ | ✓ | ✓ | ✓

Note: System clearance will have to be evaluated.

PCI Express M.2 Specification | | 60

The Hx naming convention along with the mechanical Key letter enables easy recognition of the required connector through simple nomenclature; as shown in the following example:

M.2 Connector H2.3-E-Opt1
- H2.3 designates the connector height, in this case the height supports a Single-sided solution (2.25 Max Ht.),
- E designates Key E,
- Opt1 designates the durability level, the minimum number of insertion/extraction cycles, in this case a minimum of 25 (see the Durability line item in Table 12 ).

This Hx descriptor also aligns with the coinciding Standoff descriptor described in the Section 2.5.

## 2.4.1. Connector Pin Count

The connector has 75 positions. However, eight positions are used for each connector key so the pin count is 67 pins.

## 2.4.2. Contact Pitch

The contact pitch is 0.5 mm. The connector will have two rows of pins, top and bottom. The bottom row is staggered by 0.25 mm from the top row.

## 2.4.3. System Connector Parametric Specifications

Table 11, 12 and 13 specify the requirements for physical, environmental, and electrical performance for the M.2 connector.

Table 11. | Connector Physical Requirements
Description | Requirement
Connector Housing | UL rated 94-V-0 Must be compatible with lead-free soldering process
Contact: Receptacle | Copper alloy with Gold Plating sufficient to meet all mechanical and environmental requirements
Contact Finish : Receptacle | Must be compatible with lead-free soldering process

PCI Express M.2 Specification | | 61
Table 12. | Connector Environmental Requirements
Test Conditions | Specification
Durability | EIA-364-9; • Option 1 - 25 cycles, • Option 2 - 60 cycles. Upon completion of cycles the sample must meet all visual and electrical performance requirements.
Insertion Force | Insertion Force-25 N (2.04 KgF, 1 Newton = 1 Kg*m/s² ) maximum EIA-364-13, Method A
Shock | • 250 G (Notebook) and 285 G (Tablet) • At 2 ms half sine • On all six (6) axis
Vibration | EIA-364-1000 Test group 3, EIA-364-28
Operating Temperature | -40°C to 80°C
Environmental Test Methodology | EIA-364-1000 Test Group 1, 2, 3, and 4
Useful Field Life | Three years
Table 13. | Connector Electrical Requirements
Description | Requirement
Low Level Contact Resistance | EIA-364-23 • 55 mΩ maximum (initial) per contact • 20 mΩ maximum change allowed
Insulation Resistance | EIA-364-21 • >5 x 108 Ω @ 500 V DC
Dielectric Withstanding Voltage | EIA-364-20 • >300 V AC (RMS) @ Sea Level
Current Rating | • 0.5 A/Power Contact (continuous) • The temperature rise above ambient shall not exceed 30°C. • The ambient condition is still air at 25°C. • EIA-364-70 Method 2
Voltage Rating | 50 V AC per Contact

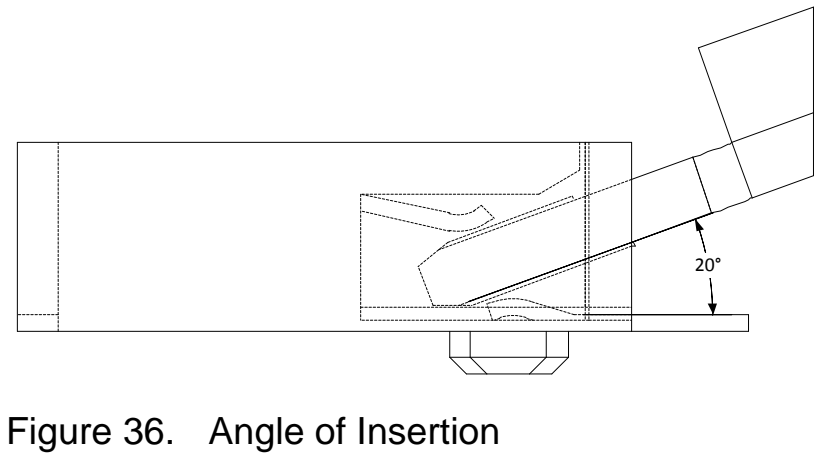
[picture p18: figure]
20° Figure 36. Angle of Insertion

PCI Express M.2 Specification | | 62

## 2.4.4. Additional Environmental Requirements

The connector must meet RoHS (no exceptions) and Low Halogen compliance.

## 2.4.5. Card Insertion

☐ Angled insertion is allowable and preferred; intent is to minimize the insertion/extraction force. The minimum of angle of insertion is 5°
☐ Minimum two step insertion is desirable; intent is to minimize the insertion/extraction force.

## 2.4.6. Point of Contact Guideline

The signal integrity and mechanical requirements yield a starting point for the point of contact to module Gold Finger relationship. The range for the upper point of contact measured from the seating plane should be between 0.8 mm to 1.3 mm and the range for the lower point of contact should be between 0.9 mm to 2.2 mm. (see Figure 37, Point of Contact).

Notwithstanding the aforementioned, the actual mechanical relationship between connector and module within a system is controlled by the platform implementer. Therefore platform implementers should pay attention to all elements of positioning connector and module to assure a proper mated condition.

Note: The angle of insertion is a key consideration for determining the point of contact; see Figure 36. Objective is to minimize insertion/removal forces while meeting signal integrity requirements.

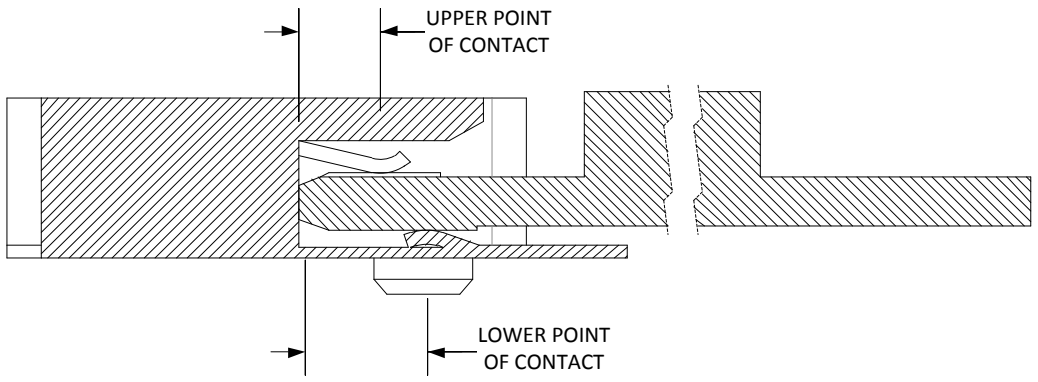
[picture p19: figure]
UPPER POINT OF CONTACT

PCI Express M.2 Specification | | 63

LOWER POINT OF CONTACT Note: Connector design and contact shape are generic and infers no design intent beyond the

dimensioned contact point.

## Figure 37. Point of Contact

## 2.4.7. Top Side Connection

## 2.4.7.1. Top Side Connector Physical Dimensions

The top-side scheme has two connectors that share a common footprint but have a different stack-up requirement (see section 2.4.7.3 for more detail)

☐ Length—22 mm maximum including land pattern
☐ Width—9.1 mm maximum including land pattern

Figure 38 shows the top-side connector dimensions.

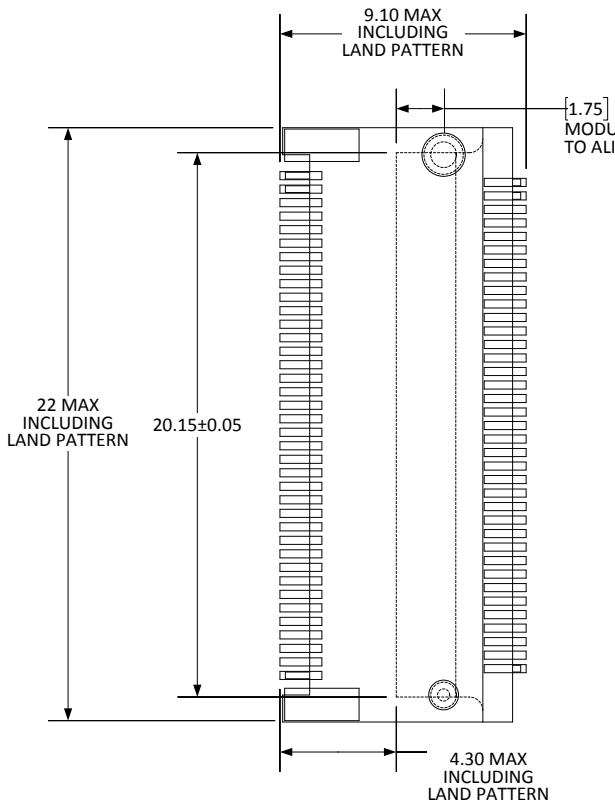
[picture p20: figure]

PCI Express M.2 Specification | | 64
A | B 4.30 MAX INCLUDING LAND PATTERN

20.15±0.05 22 MAX INCLUDING LAND PATTERN

9.10 MAX INCLUDING LAND PATTERN | 1.75 MODULE SEATING PLANE TO ALIGNMENT POST

ALL DIMENSIONS mm

Height | A (MAX) | B (MAX) H2.3 | 2.25 | 0.41 H2.5 | 2.45 | 0.61 H2.8 | 2.75 | 0.89 H3.2 | 3.20 | 1.54 H4.2 | 4.20 | 2.54

## Figure 38. Top Side Connector Dimensions

PCI Express M.2 Specification | | 65

## 2.4.7.2. Top Side Connection Total System Length

The maximum total solution is constrained to module length plus the following increases:

☐ The additional increase in length is 7.05 mm maximum for top-side connector to the module length (Figure 39).
- The retention screw adds 2.75 mm maximum.
- The maximum extension, including land pattern beyond the module leading edge is 4.3 mm. ☐ Module lengths are 30 mm, 42 mm, 60 mm, 80 mm, and 110 mm.
4.30 | MODULE LENGTH | 2.75 Note: The retention screw and stand-off are required for mechanical hold down and potential

thermal path (see section 2.5, Module Stand-off for an example).

## Figure 39. Top Mounting System Length

PCI Express M.2 Specification | | 66

## 2.4.7.3. Top Side Connection Stack-up

## 2.4.7.3.1. Single Sided Module (Using H2.3 Connector)

Total solution above the main board varies based on the maximum component height on the module. Figure 40, Figure 41, and Figure 42 show the profiles based on three single-sided maximum component heights; 1.2 mm, 1.35 mm, and 1.5 mm. The maximum RSS given is calculated from the top of the main board to the top of the module.

(2.25) MAX CONNECTOR HT. | 0.30 MIN | 0.80±0.08 1.10±0.10 | 2.45 MAX RSS TOP OF MB TO TOP OF MODULE Figure 40. H2.3-S1 - Stack-up Top Mount Single-Sided Module for

## 1.2 Maximum Component Height

(2.25) MAX CONNECTOR HT. | 0.30 MIN | 0.80±0.08 1.25±0.10 | 2.60 MAX RSS TOP OF MB TO TOP OF MODULE Figure 41. H2.3-S2 - Stack-up Top Mount Single Sided Module for

## 1.35 Maximum Component Height

(2.25) MAX CONNECTOR HT. | 0.30 MIN | 0.80±0.08 1.40±0.10 | 2.75 MAX RSS TOP OF MB TO TOP OF MODULE Figure 42. H2.3-S3 - Stack-up Top Mount Single Sided Module for

## 1.50 Maximum Component Height

PCI Express M.2 Specification | | 67

## 2.4.7.3.2. Single Sided Module (Using H2.5 Connector)

Total solution above the main board varies based on the maximum component height on the module. Figure 43, Figure 44, and Figure 45 show the profiles based on three single-sided maximum component heights; 1.2 mm, 1.35 mm, and 1.5 mm. The maximum RSS given is calculated from the top of the main board to the top of the module.

## Figure 43. H2.5-S1 - Stack-up Top Mount Single-sided Module for 1.20 Maximum Top-side Component Height and with Higher Clearance above Motherboard

## Figure 44. H2.5-S2 - Stack-up Top Mount Single-sided Module for 1.35 Maximum Top-side Component Height and with Higher Clearance above Motherboard

## Figure 45. H2.5-S3 - Stack-up Top Mount Single-sided Module for 1.5 Maximum Top-side Component Height and with Higher Clearance above Motherboard

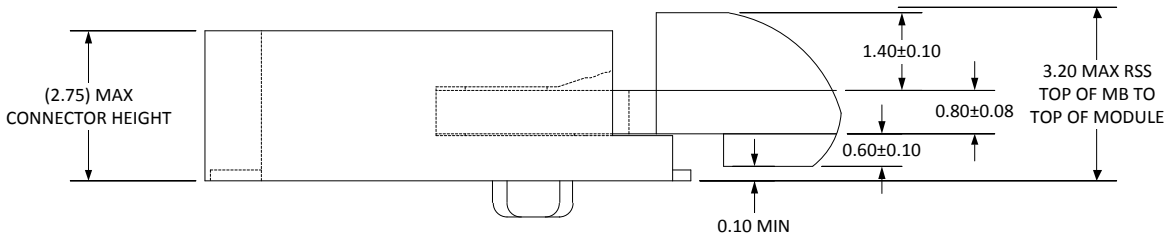
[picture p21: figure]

PCI Express M.2 Specification | | 68

## 2.4.7.3.3. Double Sided Module (Using H2.8, H3.2 and H4.2 Connector)

Total solution above the main board varies based on the maximum component height on the module. Figure 46, Figure 47, Figure 48, Figure 49, and Figure 50 show the profiles based on four top-side maximum component heights; 1.2 mm, 1.35 mm, and 1.5 mm. The bottom-side components maximum height is 1.50mm, 1.35 mm or 0.70 mm. The maximum RSS given is calculated from the top of the main board to the top of the module.

3.20 MAX RSS TOP OF MB TO TOP OF MODULE 1.40±0.10

0.80±0.08 0.10 MIN (2.75) MAX CONNECTOR HEIGHT

## Figure 46. H2.8-D4 - Stack-up Top Mount Double-sided Module for 1.5 Maximum Top-side Component Height with 0.7 Maximum Bottom-side Component Height

3.55 MAX RSS TOP OF MB TO TOP OF MODULE (3.20) MAX | 0.80±0.08 CONNECTOR HEIGHT | 1.10±0.10

## 1.25±0.10 0.10 MIN Figure 47. H3.2-D1 - Stack-up Top Mount Double-sided Module for

## 1.20 Maximum Top-side Component Height

PCI Express M.2 Specification | | 69
3.70 MAX RSS TOP OF MB TO TOP OF MODULE (3.20) MAX | 0.80±0.08 CONNECTOR HEIGHT | 1.25±0.10

## 1.25±0.10 0.10 MIN Figure 48. H3.2-D2 - Stack-up Top Mount Double-sided Module for

## 1.35 Maximum Top-side Component Height

3.85 MAX RSS TOP OF MB TO TOP OF MODULE (3.20) MAX | 0.80±0.08 CONNECTOR HEIGHT | 1.40±0.10

## 1.25±0.10 0.10 MIN Figure 49. H3.2-D3 - Stack-up Top Mount Double-sided Module for

## 1.5 Maximum Top-side Component Height

0.10 MIN | 4.85 MAX RSS BOTTOM OF MB TO TOP OF MODULE 1.40±0.10 1.40±0.10 (4.20) MAX CONNECTOR HT. | 0.80±0.08 MAIN BOARD

## Figure 50. H4.2-D5 - Stack-up Top Mount Double-sided Module for 1.5 Maximum Top-side Component Height with 1.5 Maximum Bottom-side Component Height

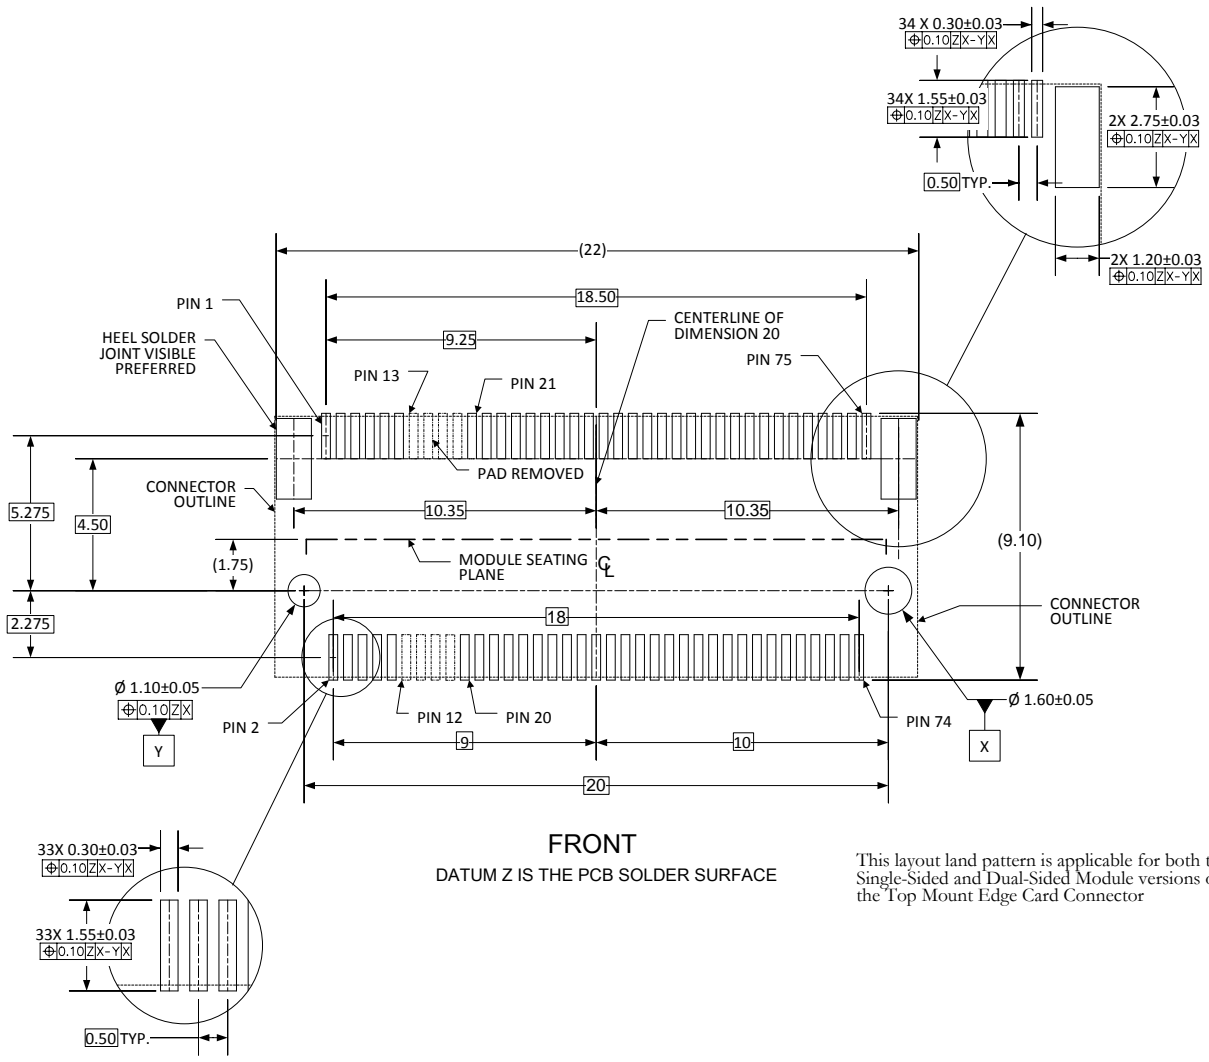
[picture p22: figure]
FRONT DATUM Z IS THE PCB SOLDER SURFACE; 2X 1.20±0.03 0.50 TYP.; 0.50 TYP.; MODULE SEATING PLANE; C CONNECTOR OUTLINE; HEEL SOLDER JOINT VISIBLE PREFERRED; PIN 1; CONNECTOR OUTLINE PIN 12; PIN 20; PIN 74 PIN 2; PIN 13; PIN 21; PAD REMOVED; PIN 75; CENTERLINE OF DIMENSION 20

PCI Express M.2 Specification | | 70

## 2.4.7.4. Top Side Connector Layout Pattern

The layout footprint of the Top Mount Host I/F Edge Card Slot connector on the platform side Mother Board is shown in Figure 51. The land pattern includes all 75 pads although only up to 67 pads will be routed out while eight (8) pads will be redundant as they are located where the Mechanical Key is located. Figure 51 shows the eight redundant pads of Key B as faded.

This layout land pattern is applicable for both the Single-Sided and Dual-Sided Module versions of the Top Mount Edge Card Connector

## Figure 51. Example of Top Mount Motherboard Land Pattern Diagram Key B Shown

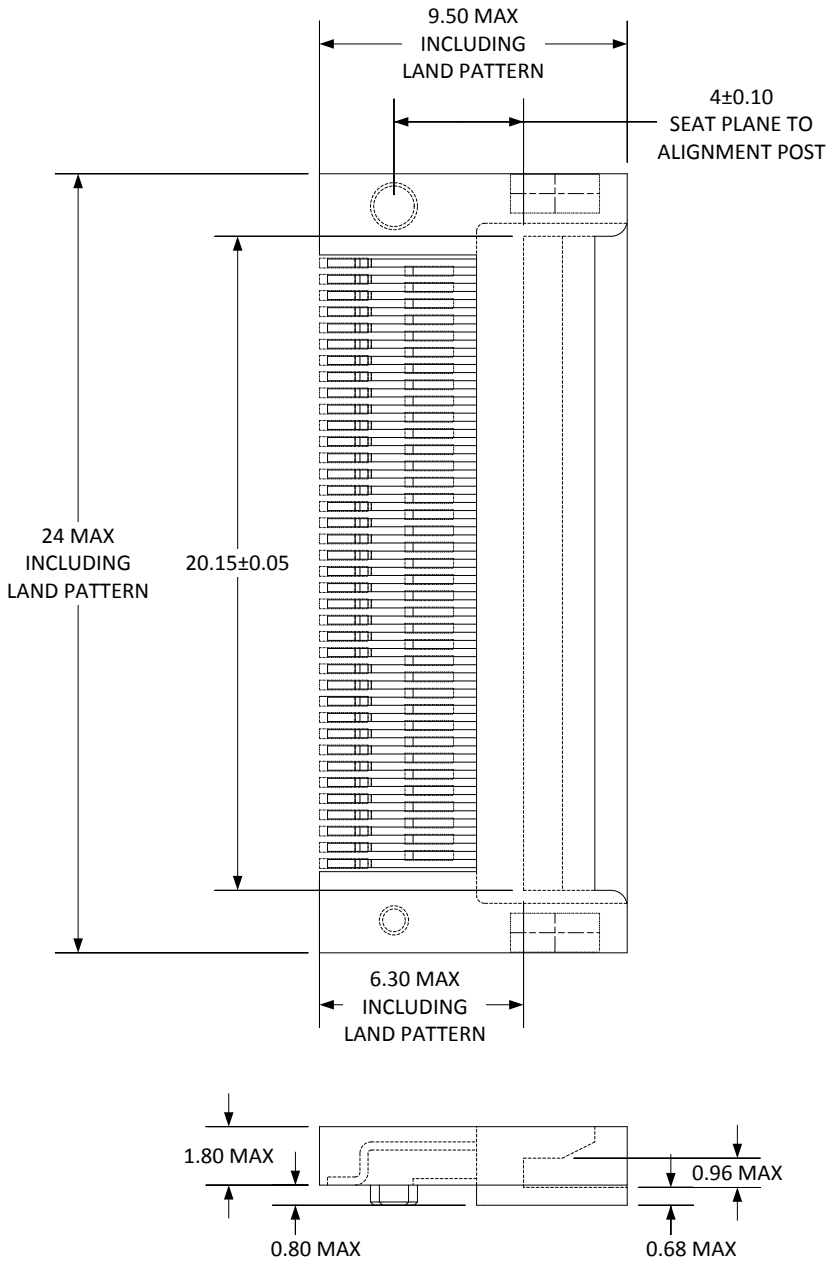
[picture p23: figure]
1.80 MAX; 0.96 MAX; 9.50 MAX INCLUDING LAND PATTERN; 6.30 MAX INCLUDING LAND PATTERN; 4±0.10 SEAT PLANE TO ALIGNMENT POST

PCI Express M.2 Specification | | 71

## 2.4.8. Mid Line Connection (Using M1.8 Connector)

## 2.4.8.1. Mid Line Connector Physical Dimensions

☐ Length-24 mm maximum including land pattern
☐ Width-9.5 mm maximum including land pattern

20.15±0.05 24 MAX INCLUDING LAND PATTERN

0.80 MAX | 0.68 MAX Figure 52. Mid-Line (In-line) Connector Dimensions

PCI Express M.2 Specification | | 72

## 2.4.8.2. Mid Line Connection Total System Length

The maximum total solution is constrained to module length plus the following increases:

☐ The additional increase in length is 9.05 mm for top-side connector to the module length.
- The retention screw adds 2.75 mm maximum.
- The maximum extension, including land pattern beyond the module leading edge is 6.3 mm. ☐ Module lengths are 30 mm, 42 mm, 60 mm, 80 mm, and 110 mm.
6.30 | LENGTH | 2.75 Figure 53. Mid-Line (In-Line) System Length

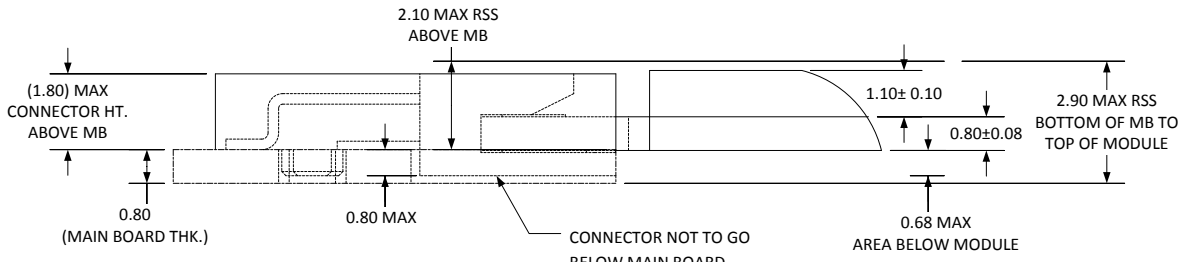
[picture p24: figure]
0.80 (MAIN BOARD THK.); 2.10 MAX RSS ABOVE MB

PCI Express M.2 Specification | | 73

## 2.4.8.3. Mid Line Connection Stack-up

## 2.4.8.3.1. Single-sided Module

Total solution above the main board varies based on the maximum component height on the module. Figure 54, Figure 55, and Figure 56 show the profiles based on three single-sided maximum component heights; 1.2 mm, 1.35 mm, and 1.5 mm. The maximum RSS given is measured from the top of the main board to the top of the module. Also given is the maximum RSS as calculated from the bottom of the main board to top of the module.

1.10± 0.10 | 2.90 MAX RSS BOTTOM OF MB TO TOP OF MODULE 0.80±0.08 (1.80) MAX CONNECTOR HT. ABOVE MB
0.68 MAX AREA BELOW MODULE 0.80 MAX | CONNECTOR NOT TO GO BELOW MAIN BOARD Figure 54. Stack-up Mid-Line (In-line) Single Sided (S1) Module for

## 1.2 Maximum Component Height

3.05 MAX RSS BOTTOM OF MB TO TOP OF MODULE ².25 MAX RSS ABOVE MB (1.80) MAX CONNECTOR HT. ABOVE MB

0.80±0.08 0.68 MAX AREA BELOW MODULE CONNECTOR NOT TO GO BELOW MAIN BOARD Figure 55. Stack-up Mid-Line (In-line) Single Sided (S2) Module for

## 1.35 Maximum Component Height

PCI Express M.2 Specification | | 74
Revision 1.0, November 1, 2013 | 3.20 MAX RSS BOTTOM OF MB TO TOP OF MODULE ².40 MAX RSS ABOVE MB (1.80) MAX CONNECTOR HT. ABOVE MB

0.80±0.08 0.68 MAX AREA BELOW MODULE CONNECTOR NOT TO GO BELOW MAIN BOARD Figure 56. Stack-up Mid-Line (In-line) Single Sided (S3) Module for

## 1.5 Maximum Component Height

## 2.4.8.3.2. Double-sided Module

Total solution above the main board varies based on the maximum component height on the module. Figure 57 through Figure 61 show the profiles based on three top-side maximum component heights; 1.2 mm, 1.35 mm, and 1.5 mm. The bottom-side components maximum height is 1.5 mm, 1.35 mm, or 0.7mm. The maximum RSS given is calculated from the top of the main board to the top of the module.

0.80± 0.08 ¹.10± 0.10 ⁽¹.80) MAX CONNECTOR HT. ABOVE MB

## (0.47) Figure 57. Stack-up Mid-Line (In-line) Double-sided (D1) Module for

## 1.2 Maximum Top-side Component Height

PCI Express M.2 Specification | | 75

2.25 MAX RSS ABOVE MB (1.80) MAX CONNECTOR HT. ABOVE MB

0.80 (MAIN BOARD THK.) | (0.47) | 1.25±0.10 0.80±0.08 0.80 MAX | 1.25± 0.10 Figure 58. Stack-up Mid-Line (In-line) Double-sided (D2) Module for

## 1.35 Maximum Top-side Component Height

2.40 MAX RSS ABOVE THE MB (1.80) MAX CONNECTOR HT. ABOVE MB

0.80 (MAIN BOARD THK.) | (0.55) | 0.80± 0.08 0.80 MAX | 1.40± 0.10 1.25± 0.10 Figure 59. Stack-up Mid-Line (In-line) Double-sided (D3) Module for

## 1.5 Maximum Top-side Component Height

2.40 MAX RSS ABOVE THE MB (1.80) MAX CONNECTOR HT. ABOVE MB

## 0.60±0.10 0.80 MAX Figure 60. Stack-up Mid-Line (In-line) Double-sided (D4) Module for

## 1.5 Maximum Top-side Component Height

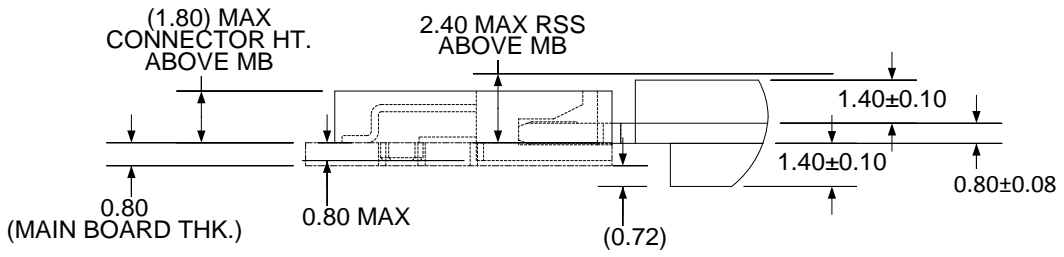
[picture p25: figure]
2.40 MAX RSS ABOVE MB; (1.80) MAX CONNECTOR HT. ABOVE MB

PCI Express M.2 Specification | | 76

1.40±0.10 0.80 MAX 0.80 (MAIN BOARD THK.)

## Figure 61. Stack-up Mid-Line (In-line) Double-sided (D5) Module for 1.5 Maximum Top-side and Bottom-side Component Height

## 2.4.8.4. Mid Line Connector Layout Pattern

The layout footprint of the Mid Mount Host I/F Edge Card Slot connector on the platform side Mother Board is shown in the following diagram. The land pattern includes all 75 pads although only up to 67 pads will be routed out while 8 pads will be redundant as they are located where the Mechanical Key is located. Figure 62 shows the eight redundant pads of Key B as faded.

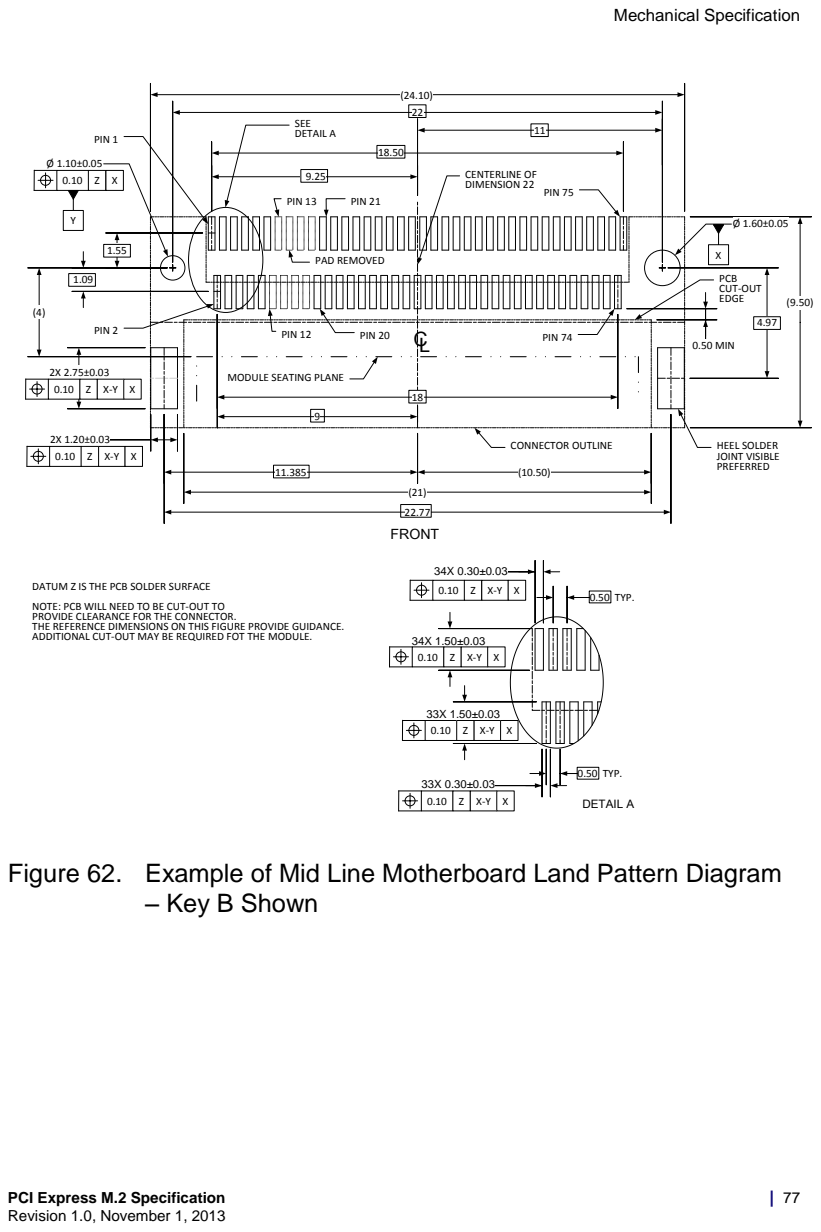
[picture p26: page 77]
PCI Express M.2 Specification; DATUM Z IS THE PCB SOLDER SURFACE NOTE: PCB WILL NEED TO BE CUT-OUT TO PROVIDE CLEARANCE FOR THE CONNECTOR. THE REFERENCE DIMENSIONS ON THIS FIGURE PROVIDE GUIDANCE. ADDITIONAL CUT-OUT MAY BE REQUIRED FOT THE MODULE.; 0.50 TYP.; DETAIL A; FRONT; 0.50 MIN; CONNECTOR OUTLINE MODULE SEATING PLANE 0.10; PAD REMOVED PIN 12; PIN 20 PIN 2; PIN 1; SEE DETAIL A; PIN 13; PIN 21; PIN 75; PIN 74; – Key B Shown

CENTERLINE OF DIMENSION 22

PCB CUT-OUT EDGE CL

HEEL SOLDER JOINT VISIBLE PREFERRED

Figure 62. Example of Mid Line Motherboard Land Pattern Diagram

PCI Express M.2 Specification | | 78

## 2.4.9. Connector Key Dimension

The width of the key is shown in Figure 63.

## A 1.10±0.03 Figure 63. Connector Key

## 2.4.9.1. Host Connector Keying

The generic 75 position edge card connector on the mother board side will incorporate a mechanical keying scheme to enable mating with only a matching keyed module. This mechanical key uses up eight pin locations (four on the topside and four on the bottom side). The generic 75-pin connector is able to accommodate 12 different mechanical Keys that are designated by a Letter. Each such Keyed connector will have 67 usable pins available but at alternate pin locations within the generic 75 pin locations.

The Mechanical Key mechanism will enable the following:

☐ Each Socket on the Motherboard with a different mechanical key location to signify a different pin-out and functionality of that particular socket
☐ To prevent wrongful insertion of an incompatible module into a wrong Socket connector on the Motherboard. Including the potential module inversion. This is required for Safety reasons
☐ Multiple module key schemes that will enable insertion into more than one Socket

Mechanical keyed connectors that have their key locations within the first 49 pins (A, B, C, D, E, F, G, and H) can also accommodate the smaller 49 pin versions of the M.2 form factors like the Type 1630 board/module size. These smaller modules, which probably contain less content and require the reduced pin count, could still be plugged into the same Motherboard keyed socket as their larger counterparts but enable module vendors a cost saving opportunity in the form of a smaller module for such simplistic solutions.

Figure 64 shows the relative location of the Mechanical Keys along the 75 positions. The Green and Blue marked areas are the locations of a reversed board showing that they do not coincide with the upright location of Keys. By assigning Key locations and making sure they are not interchangeable (upright or reversible), we end up with 12 distinct Keys.

PCI Express M.2 Specification | | 79
Figure 64. M.2 Connector Keying Diagram Top Row | Pin 75 | Pin 74 | Pin 73 | Pin 72 | Pin 71 | Pin 70 | Pin 69 | Pin 68 | Pin 67 | Pin 66 | Pin 65 | Pin 64 | Pin 63 | Pin 62 | Pin 61 | Pin 60 | Pin 59 | Pin 58 | Pin 57 | Pin 56 | Pin 55 | Pin 54 | Pin 53 | Pin 52 | Pin 51 | Pin 50 | Pin 49 | Pin 48 | Pin 47 | Pin 46 | Pin 45 | Pin 44 | Pin 43 | Pin 42 | Pin 41 | Pin 40 | Pin 39 | Pin 38 | Pin 37 | Pin 36 | Pin 35 | Pin 34 | Pin 33 | Pin 32 | Pin 31 | Pin 30 | Pin 29 | Pin 28 | Pin 27 | Pin 26 | Pin 25 | Pin 24 | Pin 23 | Pin 22 | Pin 21 | Pin 20 | Pin 19 | Pin 18 | Pin 17 | Pin 16 | Pin 15 | Pin 14 | Pin 13 | Pin 12 | Pin 11 | Pin 10 | Pin 9 | Pin 8 | Pin 7 | Pin 6 | Pin 5 | Pin 4 | Pin 3 | Pin 2 | pin 1 Bottom Row
59 | 66 Top Row | Pin 75 | Pin 74 | Pin 73 | Pin 72 | Pin 71 | Pin 70 | Pin 69 | Pin 68 | Pin 67 | Pin 66 | Pin 65 | Pin 64 | Pin 63 | Pin 62 | Pin 61 | Pin 60 | Pin 59 | Pin 58 | Pin 57 | Pin 56 | Pin 55 | Pin 54 | Pin 53 | Pin 52 | Pin 51 | Pin 50 | Pin 49 | Pin 48 | Pin 47 | Pin 46 | Pin 45 | Pin 44 | Pin 43 | Pin 42 | Pin 41 | Pin 40 | Pin 39 | Pin 38 | Pin 37 | Pin 36 | Pin 35 | Pin 34 | Pin 33 | Pin 32 | Pin 31 | Pin 30 | Pin 29 | Pin 28 | Pin 27 | Pin 26 | Pin 25 | Pin 24 | Pin 23 | Pin 22 | Pin 21 | Pin 20 | Pin 19 | Pin 18 | Pin 17 | Pin 16 | Pin 15 | Pin 14 | Pin 13 | Pin 12 | Pin 11 | Pin 10 | Pin 9 | Pin 8 | Pin 7 | Pin 6 | Pin 5 | Pin 4 | Pin 3 | Pin 2 | pin 1 Bottom Row
55 | 62 Top Row | Pin 75 | Pin 74 | Pin 73 | Pin 72 | Pin 71 | Pin 70 | Pin 69 | Pin 68 | Pin 67 | Pin 66 | Pin 65 | Pin 64 | Pin 63 | Pin 62 | Pin 61 | Pin 60 | Pin 59 | Pin 58 | Pin 57 | Pin 56 | Pin 55 | Pin 54 | Pin 53 | Pin 52 | Pin 51 | Pin 50 | Pin 49 | Pin 48 | Pin 47 | Pin 46 | Pin 45 | Pin 44 | Pin 43 | Pin 42 | Pin 41 | Pin 40 | Pin 39 | Pin 38 | Pin 37 | Pin 36 | Pin 35 | Pin 34 | Pin 33 | Pin 32 | Pin 31 | Pin 30 | Pin 29 | Pin 28 | Pin 27 | Pin 26 | Pin 25 | Pin 24 | Pin 23 | Pin 22 | Pin 21 | Pin 20 | Pin 19 | Pin 18 | Pin 17 | Pin 16 | Pin 15 | Pin 14 | Pin 13 | Pin 12 | Pin 11 | Pin 10 | Pin 9 | Pin 8 | Pin 7 | Pin 6 | Pin 5 | Pin 4 | Pin 3 | Pin 2 | pin 1 Bottom Row
51 | 58 Top Row | Pin 75 | Pin 74 | Pin 73 | Pin 72 | Pin 71 | Pin 70 | Pin 69 | Pin 68 | Pin 67 | Pin 66 | Pin 65 | Pin 64 | Pin 63 | Pin 62 | Pin 61 | Pin 60 | Pin 59 | Pin 58 | Pin 57 | Pin 56 | Pin 55 | Pin 54 | Pin 53 | Pin 52 | Pin 51 | Pin 50 | Pin 49 | Pin 48 | Pin 47 | Pin 46 | Pin 45 | Pin 44 | Pin 43 | Pin 42 | Pin 41 | Pin 40 | Pin 39 | Pin 38 | Pin 37 | Pin 36 | Pin 35 | Pin 34 | Pin 33 | Pin 32 | Pin 31 | Pin 30 | Pin 29 | Pin 28 | Pin 27 | Pin 26 | Pin 25 | Pin 24 | Pin 23 | Pin 22 | Pin 21 | Pin 20 | Pin 19 | Pin 18 | Pin 17 | Pin 16 | Pin 15 | Pin 14 | Pin 13 | Pin 12 | Pin 11 | Pin 10 | Pin 9 | Pin 8 | Pin 7 | Pin 6 | Pin 5 | Pin 4 | Pin 3 | Pin 2 | pin 1 | WWAN/SSD/OTHER PRIMARY KEY Bottom Row
47 | 54 Top Row | Pin 75 | Pin 74 | Pin 73 | Pin 72 | Pin 71 | Pin 70 | Pin 69 | Pin 68 | Pin 67 | Pin 66 | Pin 65 | Pin 64 | Pin 63 | Pin 62 | Pin 61 | Pin 60 | Pin 59 | Pin 58 | Pin 57 | Pin 56 | Pin 55 | Pin 54 | Pin 53 | Pin 52 | Pin 51 | Pin 50 | Pin 49 | Pin 48 | Pin 47 | Pin 46 | Pin 45 | Pin 44 | Pin 43 | Pin 42 | Pin 41 | Pin 40 | Pin 39 | Pin 38 | Pin 37 | Pin 36 | Pin 35 | Pin 34 | Pin 33 | Pin 32 | Pin 31 | Pin 30 | Pin 29 | Pin 28 | Pin 27 | Pin 26 | Pin 25 | Pin 24 | Pin 23 | Pin 22 | Pin 21 | Pin 20 | Pin 19 | Pin 18 | Pin 17 | Pin 16 | Pin 15 | Pin 14 | Pin 13 | Pin 12 | Pin 11 | Pin 10 | Pin 9 | Pin 8 | Pin 7 | Pin 6 | Pin 5 | Pin 4 | Pin 3 | Pin 2 | pin 1 Bottom Row
43 | 50 Top Row | Pin 75 | Pin 74 | Pin 73 | Pin 72 | Pin 71 | Pin 70 | Pin 69 | Pin 68 | Pin 67 | Pin 66 | Pin 65 | Pin 64 | Pin 63 | Pin 62 | Pin 61 | Pin 60 | Pin 59 | Pin 58 | Pin 57 | Pin 56 | Pin 55 | Pin 54 | Pin 53 | Pin 52 | Pin 51 | Pin 50 | Pin 49 | Pin 48 | Pin 47 | Pin 46 | Pin 45 | Pin 44 | Pin 43 | Pin 42 | Pin 41 | Pin 40 | Pin 39 | Pin 38 | Pin 37 | Pin 36 | Pin 35 | Pin 34 | Pin 33 | Pin 32 | Pin 31 | Pin 30 | Pin 29 | Pin 28 | Pin 27 | Pin 26 | Pin 25 | Pin 24 | Pin 23 | Pin 22 | Pin 21 | Pin 20 | Pin 19 | Pin 18 | Pin 17 | Pin 16 | Pin 15 | Pin 14 | Pin 13 | Pin 12 | Pin 11 | Pin 10 | Pin 9 | Pin 8 | Pin 7 | Pin 6 | Pin 5 | Pin 4 | Pin 3 | Pin 2 | pin 1 Bottom Row
39 | 46 Top Row | Pin 75 | Pin 74 | Pin 73 | Pin 72 | Pin 71 | Pin 70 | Pin 69 | Pin 68 | Pin 67 | Pin 66 | Pin 65 | Pin 64 | Pin 63 | Pin 62 | Pin 61 | Pin 60 | Pin 59 | Pin 58 | Pin 57 | Pin 56 | Pin 55 | Pin 54 | Pin 53 | Pin 52 | Pin 51 | Pin 50 | Pin 49 | Pin 48 | Pin 47 | Pin 46 | Pin 45 | Pin 44 | Pin 43 | Pin 42 | Pin 41 | Pin 40 | Pin 39 | Pin 38 | Pin 37 | Pin 36 | Pin 35 | Pin 34 | Pin 33 | Pin 32 | Pin 31 | Pin 30 | Pin 29 | Pin 28 | Pin 27 | Pin 26 | Pin 25 | Pin 24 | Pin 23 | Pin 22 | Pin 21 | Pin 20 | Pin 19 | Pin 18 | Pin 17 | Pin 16 | Pin 15 | Pin 14 | Pin 13 | Pin 12 | Pin 11 | Pin 10 | Pin 9 | Pin 8 | Pin 7 | Pin 6 | Pin 5 | Pin 4 | Pin 3 | Pin 2 | pin 1 Bottom Row
28 | 35 Top Row | Pin 75 | Pin 74 | Pin 73 | Pin 72 | Pin 71 | Pin 70 | Pin 69 | Pin 68 | Pin 67 | Pin 66 | Pin 65 | Pin 64 | Pin 63 | Pin 62 | Pin 61 | Pin 60 | Pin 59 | Pin 58 | Pin 57 | Pin 56 | Pin 55 | Pin 54 | Pin 53 | Pin 52 | Pin 51 | Pin 50 | Pin 49 | Pin 48 | Pin 47 | Pin 46 | Pin 45 | Pin 44 | Pin 43 | Pin 42 | Pin 41 | Pin 40 | Pin 39 | Pin 38 | Pin 37 | Pin 36 | Pin 35 | Pin 34 | Pin 33 | Pin 32 | Pin 31 | Pin 30 | Pin 29 | Pin 28 | Pin 27 | Pin 26 | Pin 25 | Pin 24 | Pin 23 | Pin 22 | Pin 21 | Pin 20 | Pin 19 | Pin 18 | Pin 17 | Pin 16 | Pin 15 | Pin 14 | Pin 13 | Pin 12 | Pin 11 | Pin 10 | Pin 9 | Pin 8 | Pin 7 | Pin 6 | Pin 5 | Pin 4 | Pin 3 | Pin 2 | pin 1 Bottom Row
24 | 31 Top Row | Pin 75 | Pin 74 | Pin 73 | Pin 72 | Pin 71 | Pin 70 | Pin 69 | Pin 68 | Pin 67 | Pin 66 | Pin 65 | Pin 64 | Pin 63 | Pin 62 | Pin 61 | Pin 60 | Pin 59 | Pin 58 | Pin 57 | Pin 56 | Pin 55 | Pin 54 | Pin 53 | Pin 52 | Pin 51 | Pin 50 | Pin 49 | Pin 48 | Pin 47 | Pin 46 | Pin 45 | Pin 44 | Pin 43 | Pin 42 | Pin 41 | Pin 40 | Pin 39 | Pin 38 | Pin 37 | Pin 36 | Pin 35 | Pin 34 | Pin 33 | Pin 32 | Pin 31 | Pin 30 | Pin 29 | Pin 28 | Pin 27 | Pin 26 | Pin 25 | Pin 24 | Pin 23 | Pin 22 | Pin 21 | Pin 20 | Pin 19 | Pin 18 | Pin 17 | Pin 16 | Pin 15 | Pin 14 | Pin 13 | Pin 12 | Pin 11 | Pin 10 | Pin 9 | Pin 8 | Pin 7 | Pin 6 | Pin 5 | Pin 4 | Pin 3 | Pin 2 | pin 1 Bottom Row
20 | 27 Top Row Pin 75 | Pin 74 | Pin 73 | Pin 72 | Pin 71 | Pin 70 | Pin 69 | Pin 68 | Pin 67 | Pin 66 | Pin 65 | Pin 64 | Pin 63 | Pin 62 | Pin 61 | Pin 60 | Pin 59 | Pin 58 | Pin 57 | Pin 56 | Pin 55 | Pin 54 | Pin 53 | Pin 52 | Pin 51 | Pin 50 | Pin 49 | Pin 48 | Pin 47 | Pin 46 | Pin 45 | Pin 44 | Pin 43 | Pin 42 | Pin 41 | Pin 40 | Pin 39 | Pin 38 | Pin 37 | Pin 36 | Pin 35 | Pin 34 | Pin 33 | Pin 32 | Pin 31 | Pin 30 | Pin 29 | Pin 28 | Pin 27 | Pin 26 | Pin 25 | Pin 24 | Pin 23 | Pin 22 | Pin 21 | Pin 20 | Pin 19 | Pin 18 | Pin 17 | Pin 16 | Pin 15 | Pin 14 | Pin 13 | Pin 12 | Pin 11 | Pin 10 | Pin 9 | Pin 8 | Pin 7 | Pin 6 | Pin 5 | Pin 4 | Pin 3 | Pin 2 | pin 1 Bottom Row
16 | 23 Top Row Pin 75 | Pin 74 | Pin 73 | Pin 72 | Pin 71 | Pin 70 | Pin 69 | Pin 68 | Pin 67 | Pin 66 | Pin 65 | Pin 64 | Pin 63 | Pin 62 | Pin 61 | Pin 60 | Pin 59 | Pin 58 | Pin 57 | Pin 56 | Pin 55 | Pin 54 | Pin 53 | Pin 52 | Pin 51 | Pin 50 | Pin 49 | Pin 48 | Pin 47 | Pin 46 | Pin 45 | Pin 44 | Pin 43 | Pin 42 | Pin 41 | Pin 40 | Pin 39 | Pin 38 | Pin 37 | Pin 36 | Pin 35 | Pin 34 | Pin 33 | Pin 32 | Pin 31 | Pin 30 | Pin 29 | Pin 28 | Pin 27 | Pin 26 | Pin 25 | Pin 24 | Pin 23 | Pin 22 | Pin 21 | Pin 20 | Pin 19 | Pin 18 | Pin 17 | Pin 16 | Pin 15 | Pin 14 | Pin 13 | Pin 12 | Pin 11 | Pin 10 | Pin 9 | Pin 8 | Pin 7 | Pin 6 | Pin 5 | Pin 4 | Pin 3 | Pin 2 | pin 1 Bottom Row
12 | 19 Top Row Pin 75 | Pin 74 | Pin 73 | Pin 72 | Pin 71 | Pin 70 | Pin 69 | Pin 68 | Pin 67 | Pin 66 | Pin 65 | Pin 64 | Pin 63 | Pin 62 | Pin 61 | Pin 60 | Pin 59 | Pin 58 | Pin 57 | Pin 56 | Pin 55 | Pin 54 | Pin 53 | Pin 52 | Pin 51 | Pin 50 | Pin 49 | Pin 48 | Pin 47 | Pin 46 | Pin 45 | Pin 44 | Pin 43 | Pin 42 | Pin 41 | Pin 40 | Pin 39 | Pin 38 | Pin 37 | Pin 36 | Pin 35 | Pin 34 | Pin 33 | Pin 32 | Pin 31 | Pin 30 | Pin 29 | Pin 28 | Pin 27 | Pin 26 | Pin 25 | Pin 24 | Pin 23 | Pin 22 | Pin 21 | Pin 20 | Pin 19 | Pin 18 | Pin 17 | Pin 16 | Pin 15 | Pin 14 | Pin 13 | Pin 12 | Pin 11 | Pin 10 | Pin 9 | Pin 8 | Pin 7 | Pin 6 | Pin 5 | Pin 4 | Pin 3 | Pin 2 | pin 1 Bottom Row
8 | 15 | M

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
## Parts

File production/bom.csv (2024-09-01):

Designator | Footprint | Quantity | Value | LCSC Part #
C1.1, C1.2, C1.3, C3.2 | 0402 | 4 | 10uF
C2 | 0402 | 1 | 1000pF
C3.1 | 0402 | 1 | 100nF
C3.3 | 0402 | 1 | 22uF
D1 | D_SOD-323 | 1 | D_Schottky
F1 | 0603 | 1 | 500mA
J1 | M.2-2242-B+M-KEY_USB-ONLY | 1 | Bus_M.2_Socket_B+M_USB_Only
J101 | USB-A-S-RA-TSMT | 1 | USB_A
L1 | 1008 | 1 | 2.2uH
R1 | 0402 | 1 | 5
TP1 | TestPoint_Pad_D1.0mm | 1 | GND
TP2 | TestPoint_Pad_D1.0mm | 1 | 3V3
TP3 | TestPoint_Pad_D1.0mm | 1 | 5V
TP4 | TestPoint_Pad_D1.0mm | 1 | D+
TP5 | TestPoint_Pad_D1.0mm | 1 | D-
U1 | SOT-23-5 | 1 | TPS613222ADBV

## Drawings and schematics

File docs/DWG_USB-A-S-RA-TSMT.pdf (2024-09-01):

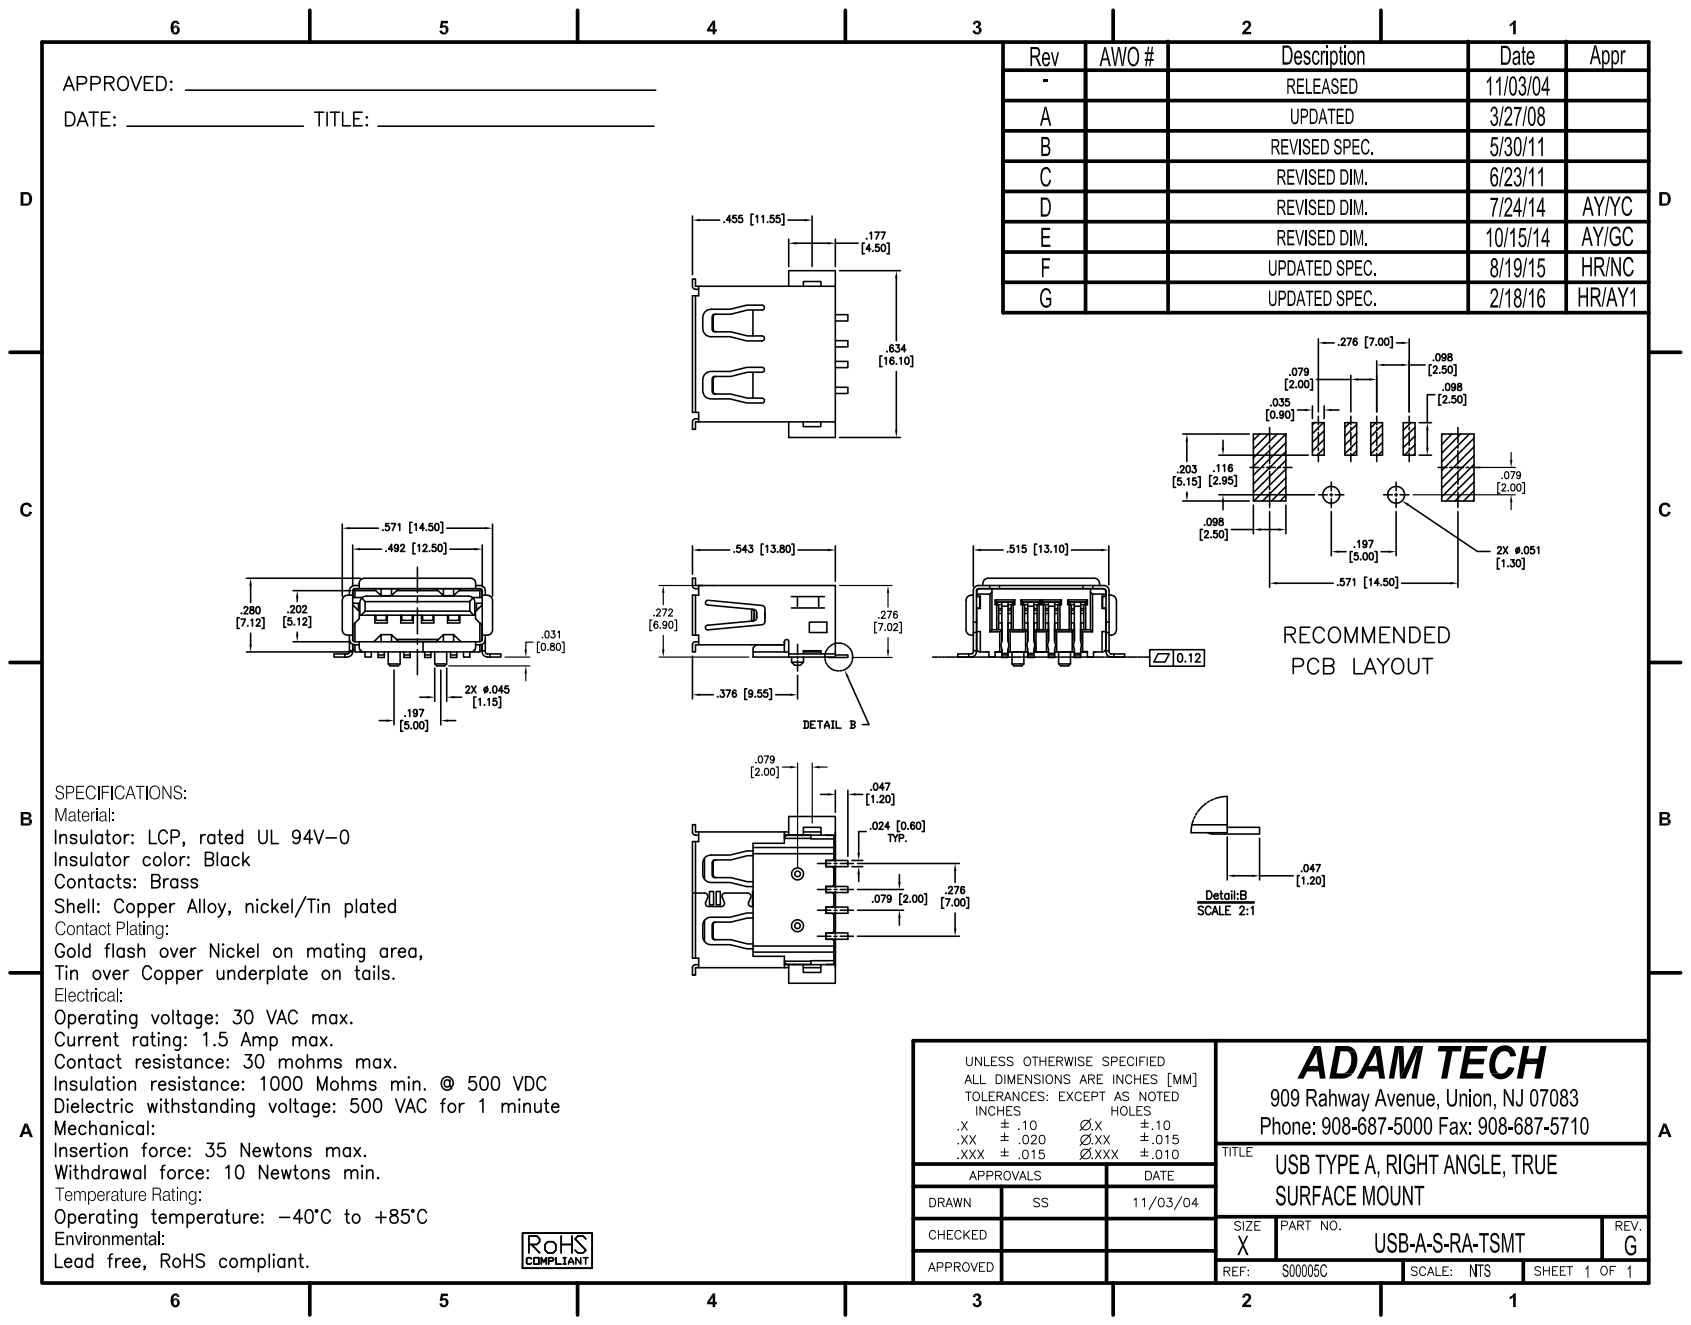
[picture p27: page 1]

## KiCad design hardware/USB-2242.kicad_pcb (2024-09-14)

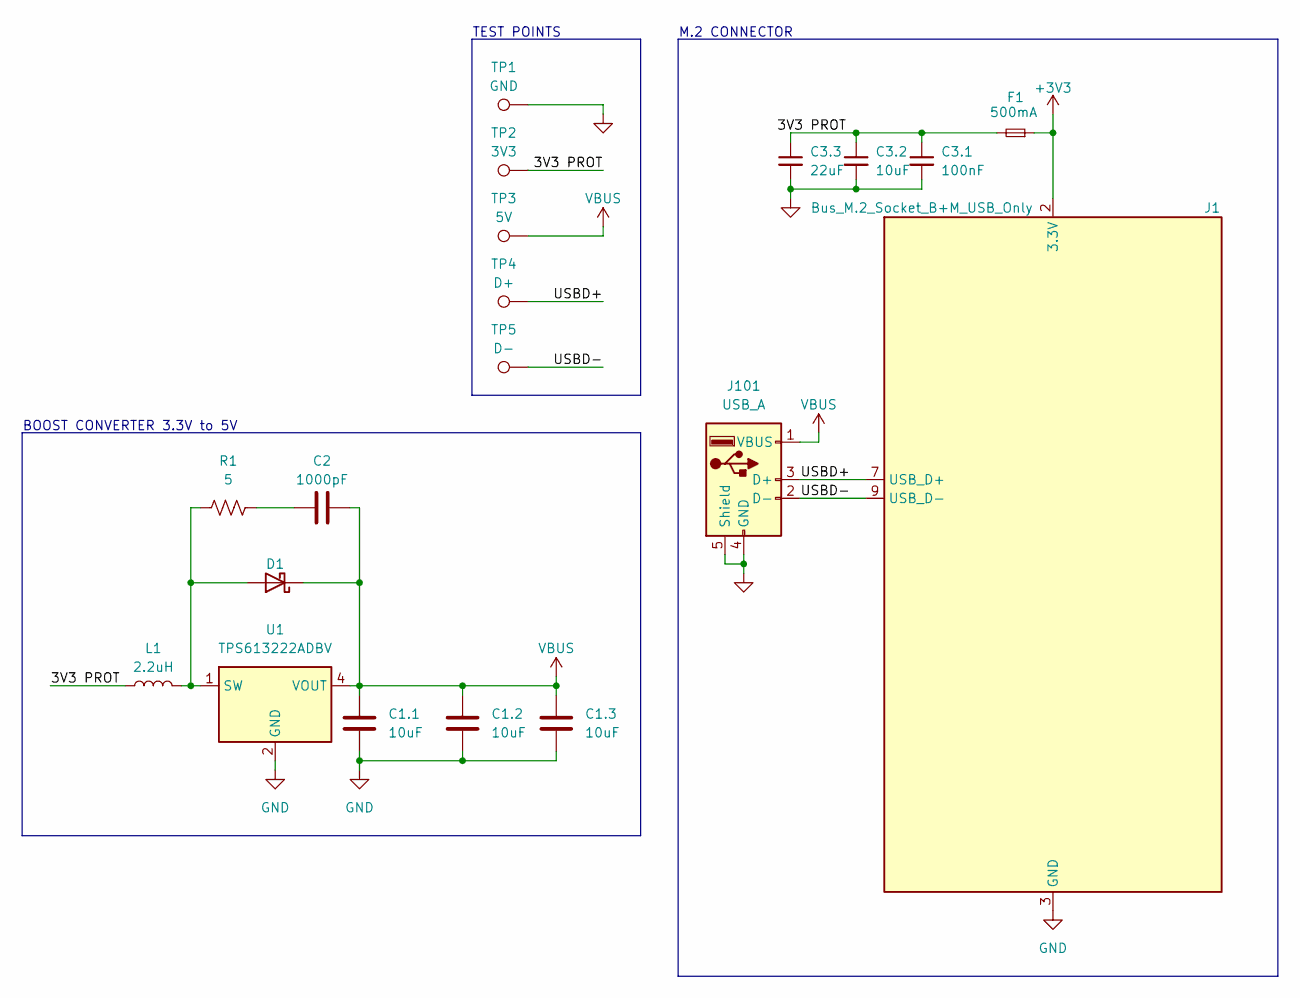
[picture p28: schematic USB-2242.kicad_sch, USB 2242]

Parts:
C1.1, C1.2, C1.3, C3.2: 10uF; C_0402_1005Metric_Pad0.74x0.62mm_HandSolder
C2: 1000pF; C_0402_1005Metric_Pad0.74x0.62mm_HandSolder
C3.1: 100nF; C_0402_1005Metric_Pad0.74x0.62mm_HandSolder
C3.3: 22uF; C_0402_1005Metric_Pad0.74x0.62mm_HandSolder
D1: D_Schottky; D_SOD-323
F1: 500mA; Fuse_0603_1608Metric_Pad1.05x0.95mm_HandSolder
J1: Bus_M.2_Socket_B+M_USB_Only; M.2-2242-B+M-KEY_USB-ONLY
J101: USB_A; USB-A-S-RA-TSMT
L1: 2.2uH; L_1008_2520Metric_Pad1.43x2.20mm_HandSolder
R1: 5; R_0402_1005Metric_Pad0.72x0.64mm_HandSolder
TP1: GND; TestPoint_Pad_D1.0mm
TP2: 3V3; TestPoint_Pad_D1.0mm
TP3: 5V; TestPoint_Pad_D1.0mm
TP4: D+; TestPoint_Pad_D1.0mm
TP5: D-; TestPoint_Pad_D1.0mm
U1: TPS613222ADBV; SOT-23-5

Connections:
+3V3: F1.1, J1.2 (3.3V), J1.4 (3.3V), J1.70 (3.3V), J1.72 (3.3V), J1.74 (3.3V)
/3V3 PROT: C3.1.1, C3.2.1, C3.3.1, F1.2, L1.1, TP2.1
/USBD+: J1.7 (USB_D+), J101.3 (D+), TP4.1
/USBD-: J1.9 (USB_D-), J101.2 (D-), TP5.1
GND: C1.1.2, C1.2.2, C1.3.2, C3.1.2, C3.2.2, C3.3.2, J1.3 (GND), J1.5 (GND), J1.11 (GND), J1.27 (GND), J1.33 (GND), J1.39 (GND), J1.45 (GND), J1.51 (GND), J1.57 (GND), J1.71 (GND), J1.73 (GND), J101.4 (GND), J101.5 (Shield), TP1.1, U1.2 (GND)
unnamed: C2.1, R1.2
unnamed: D1.2 (A), L1.2, R1.1, U1.1 (SW)
VBUS: C1.1.1, C1.2.1, C1.3.1, C2.2, D1.1 (K), J101.1 (VBUS), TP3.1, U1.4 (VOUT)

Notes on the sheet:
M.2 CONNECTOR
TEST POINTS
BOOST CONVERTER 3.3V to 5V

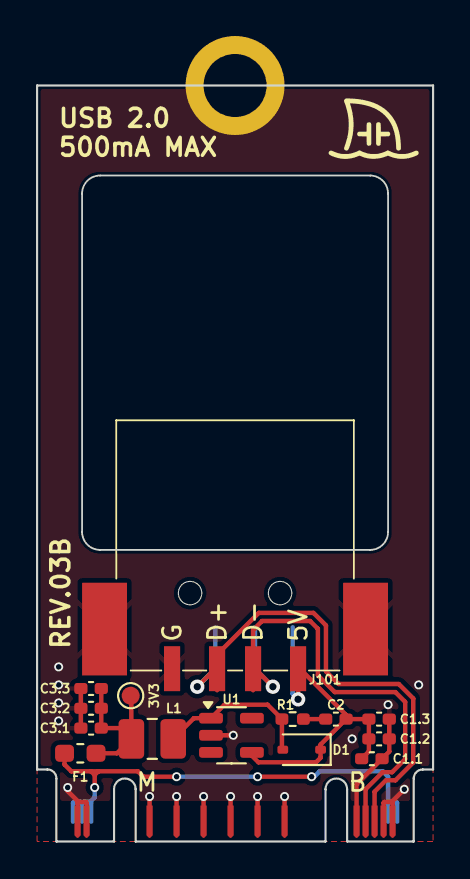
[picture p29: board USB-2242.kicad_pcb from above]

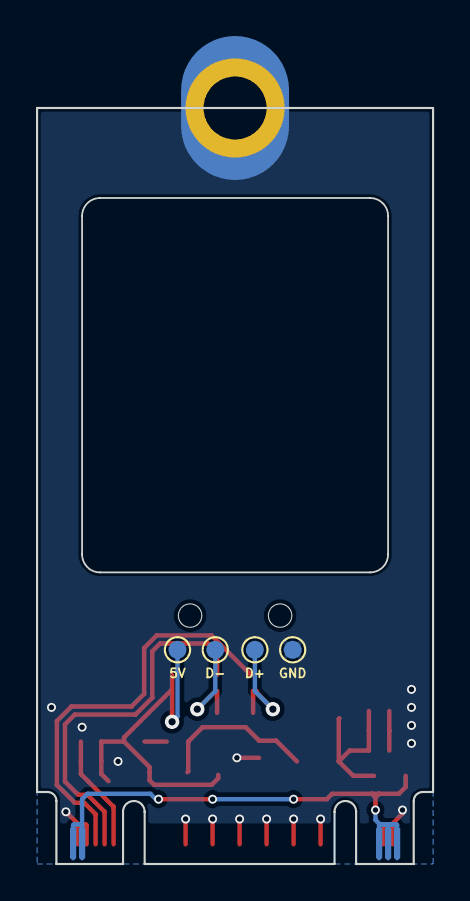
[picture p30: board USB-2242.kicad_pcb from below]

Board: 2 copper layers, 22.0 x 42.0 mm, 19 parts (4 on the bottom side), 8 nets.

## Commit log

2023-01-28 Fix overlapping pad in M.2 footprints
2023-01-28 Finish layout and routing
    [Logitech Unifying 2242.kicad_pcb, Logitech Unifying 2242.kicad_sch]
2023-01-28 Add PCB text
    [Logitech Unifying 2242.kicad_pcb]
2023-01-28 Reduce fill clearance and add more GND vias
    [Logitech Unifying 2242.kicad_pcb]
2023-01-28 Add gerber files
    [Logitech Unifying 2242-CuBottom.gbr, Logitech Unifying 2242-CuTop.gbr, Logitech Unifying 2242-EdgeCuts.gbr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]
2023-02-01 Add cutout for low-clearance use
    [Logitech Unifying 2242.kicad_pcb]
2023-02-01 Update production files
    [Logitech Unifying 2242-CuBottom.gbr, Logitech Unifying 2242-CuTop.gbr, Logitech Unifying 2242-EdgeCuts.gbr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]
2023-02-04 Update BOMs
    [BOM-Logitech Unifying 2242.csv, DK_BOM.csv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]
2023-03-04 Change screw hole pad and PCB text
    [Logitech Unifying 2242.kicad_pcb]
2023-03-04 Update M.2 footprints
    [Logitech Unifying 2242.kicad_pcb, Logitech Unifying 2242.kicad_sch]
2023-03-04 Update footprint and board settings (via size, pours, etc)
    [Logitech Unifying 2242.kicad_pcb]
2023-03-05 Reroute after added fuse and new footprints
    [Logitech Unifying 2242.kicad_pcb, Logitech Unifying 2242.kicad_sch]
2023-03-05 Add test points (#1) and other finishing touches
    [Logitech Unifying 2242.kicad_pcb, Logitech Unifying 2242.kicad_sch]
2023-03-05 Add missing net names
    [Logitech Unifying 2242.kicad_pcb, Logitech Unifying 2242.kicad_sch]
2023-03-05 Update schematic date and revision
    [Logitech Unifying 2242.kicad_sch]
2023-03-05 Copper cleanup
    [Logitech Unifying 2242.kicad_pcb, Logitech Unifying 2242.kicad_sch]
2023-03-05 Update BOM
    [DK_BOM.csv]
2023-03-05 Timestamp updates
    [Logitech Unifying 2242.kicad_pcb]
2023-03-05 Move drawings/renders to CAD folder
2023-03-05 Remove random footprint
2023-03-05 Adjust ground vias
    [Logitech Unifying 2242.kicad_pcb]
2023-03-05 Small copper fixes
    [Logitech Unifying 2242.kicad_pcb]
2023-03-05 Generate gerber files
    [BOM-Logitech Unifying 2242.csv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]
2024-09-01 Change project structure
    [BOM-Logitech Unifying 2242.csv, DK_BOM.csv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]
2024-09-01 Update project name to respect trademarks
    [Logitech Unifying 2242-CuBottom.gbr, Logitech Unifying 2242-CuTop.gbr, Logitech Unifying 2242-EdgeCuts.gbr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]
2024-09-01 Replace USB port and make various minor changes to project
    [DK_BOM.csv, USB-2242.kicad_pcb, USB-2242.kicad_sch]
2024-09-01 Add notice about PCB thickness
2024-09-02 Update clearances for copper to board edge
    [USB-2242.kicad_pcb, USB-2242.kicad_sch]
2024-09-14 Clean up silkscreen
    [USB-2242.kicad_pcb]
